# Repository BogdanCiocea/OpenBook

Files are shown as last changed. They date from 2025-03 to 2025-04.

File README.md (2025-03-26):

## PCB Description

#### ESP 
ESP32-C6-WROOM-1 is a general-purpose Wi-Fi, IEEE 802.15.4, and Bluetooth LE 
module. The rich set of peripherals and high performance make the module an 
ideal choice for smart homes, industrial automation, health care, consumer electronics, etc.

#### Absolute Maximum Ratings

| Symbol  | Parameter | Min  | Max | Unit |
| --- | --- | ---- | --- | ---- |
| VDD33 | Power supply voltage | –0.3 | 3.6 | V |
| T STORE | Storage temperature  | –40  | 105 | °C |

##### CPU and On-Chip Memory
    • ESP32-C6 embedded, 32-bit RISC-V single-core microprocessor, up to 160 MHz
    • 320 KB ROM
    • 512 KB SRAM
    • 16 KB Low-power (LP) SRAM

#### W25Q512JVEIQ

External NOR flash memory offering high-density storage.

Specifications:

• Capacity: 512 Mbit (64 MB)
• Interface: SPI (Serial Peripheral Interface)
• Operating Voltage: 3.3 V
• Usage: Firmware, configuration data, graphical assets storage

#### MCP73831

Li-Po battery charger controller for efficient battery management.

Specifications:

• Charge Current: Programmable up to ~500 mA
• Charge Voltage: Fixed 4.2 V
• Input Voltage: 5 V (typically USB)
• Features: Thermal protection, automatic charge termination, LED charge status

#### XC6220A331MR-G

Low Dropout Voltage Regulator ensuring stable power.

Specifications:

• Output Voltage: 3.3 V
• Input Voltage Range: up to 6.0 V
• Current Rating: up to 700 mA

#### MAX17048G+T10

Battery Fuel Gauge IC for precise battery monitoring.

Specifications:

• Communication Interface: I²C
• Voltage Measurement Accuracy: ±7.5 mV
• Typical Current Consumption: 23 µA
• Usage: State-of-charge monitoring, battery life estimation

#### BME688

Advanced environmental sensor providing multiple parameters.

Specifications:

• Measurements: Temperature, Humidity, Pressure, VOC gas sensing
• Communication Interface: I²C
• Operating Voltage: 1.7 V – 3.6 V

#### DS3231SN

Highly accurate Real-Time Clock (RTC) module.

Specifications:

• Accuracy: ±2 ppm (~1 min/year)
• Communication Interface: I²C
• Operating Voltage: 2.3 V – 5.5 V
• Features: Integrated battery backup for uninterrupted timekeeping

#### FH34SRJ-24S-0.5SH(99)

FFC connector for reliable display connection.

Specifications:

• Pins: 24
• Pitch: 0.5 mm
• Mount Type: Surface Mount (SMD)
• Usage: Connecting E-paper displays

#### MBR0530

Schottky diode with low forward voltage.

Specifications:

• Maximum Current: 0.5 A
• Forward Voltage Drop: ~0.3-0.4 V
• Application: Reverse voltage protection, efficient switching

#### SI1308EDL-T1-GE3

Compact N-channel MOSFET for switching applications.

Specifications:

• Voltage Rating: 20 V
• Current Rating: ~2 A
• Usage: Switching operations in display driver circuits

#### CPH3225A

Supercapacitor designed for temporary backup power.

## Pins

#### SD Card (SPI)
    * pin 7 -> pin 27 (MISO)
    * pin 3 -> pin 7 (MOSI)
    * pin 2 -> pin 4 (SS_SD)
    * pin 5 -> pin 6 (SCK)

#### 3 Buttons
    • IO/BOOT on pin 15 
    • IO/CHANGE on pin 23
    • RESET on pin 3

#### Battery Charge Level
    • pin 7 -> pin 20 (SCL)
    • pin 8 -> pin 19 (SDA)

#### BME688
    • pin 6, 8, 2 -> pin 17 (I2C_PW)
    • pin 4 -> pin 20 (SCL)
    • pin 3 -> pin 19 (SDA)

##### RTC Module DS3231SN
    • pin 4 -> pin 16 (RTC_RST)
    • pin 16 -> pin 20 (SCL)
    • pin 15 -> pin 19 (SDA)
    • pin 3 -> pin 8 (INT_RTC)
    • pin 1 -> pin 9 (32KHz)

#### USB C connector & ESD protection
    • pin 1 -> pin 14 (USB_D+)
    • pin 3 -> pin 13 (USB_D-)

## Bill Of Materials (BOM):

| Component | Quantity | Price (€) | Link | Datasheet |
| :--- | --- | --- | --- | --- |
| W25Q512JVEIQ | 1 | 5.84 | https://eu.mouser.com/ProductDetail/Winbond/W25Q512JVEIQ?qs=l7cgNqFNU1jw6svr3at6tA%3D%3D | https://eu.mouser.com/datasheet/2/949/Winbond_W25Q512JV_Datasheet-3240039.pdf |
| MAX17048G+T10 | 1 | 4.28 | https://eu.mouser.com/ProductDetail/Analog-Devices-Maxim-Integrated/MAX17048G%2bT10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 | https://eu.mouser.com/datasheet/2/609/MAX17048_MAX17049-3469099.pdf |
| ESP32-C6-WROOM-1-N8 | 1 | 2.97 | https://eu.mouser.com/ProductDetail/Espressif-Systems/ESP32-C6-WROOM-1-N8?qs=8Wlm6%252BaMh8ST02Gmwp74cw%3D%3D | https://eu.mouser.com/datasheet/2/891/Espressif_ESP32_C6_WROOM_1__Datasheet_V0_1_PRELIMI-3239987.pdf |
| 112A-TAAR-R03_ATTEND | 1 | 1.05 | https://store.comet.srl.ro/Catalogue/Product/43497/ | https://store.comet.bg/download-file.php?id=27596 |
| QWIIC_RIGHT_ANGLE | 1 | 3.75 | https://eu.mouser.com/ProductDetail/Adafruit/4208?qs=PzGy0jfpSMtbScLbr0L5dw%3D%3D | https://cdn-shop.adafruit.com/datasheets/HX8340-B_N__DS_preliminary_v01_071203.pdf |
| BD5229G-TR | 1 | 0.75 | https://eu.mouser.com/ProductDetail/ROHM-Semiconductor/BD5229G-TR?qs=4kLU8WoGk0vvnhrrYwdszw%3D%3D | https://fscdn.rohm.com/en/products/databook/datasheet/ic/power/voltage_detector/bd52xxg-e.pdf |
| 1uF capacitor | 1 | 0.13 | https://eu.mouser.com/ProductDetail/TAIYO-YUDEN/MAASL105CC7105MFCA01?qs=HFfMDpzxxd1Fn%2FInbJA7vw%3D%3D | https://eu.mouser.com/datasheet/2/396/TAIYO_YUDEN_04_27_2024_c_mlcc_A_e1-3451516.pdf |
| PGB1010603MR | 6 | 0.40 | https://eu.mouser.com/ProductDetail/Littelfuse/PGB1010603MR?qs=gu7KAQ731URLg4GSnNNN7Q%3D%3D | https://www.littelfuse.com/assetdocs/pulseguard-esd-suppressors-pgb1-datasheet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 |
| MCP73831 | 1 | 0.16 | https://eu.mouser.com/ProductDetail/Microchip-Technology/MCP73831T-5ACI-OT?qs=hH%252BOa0VZEiAcgAcEkuamXg%3D%3D | https://eu.mouser.com/datasheet/2/268/MCP73831_Family_Data_Sheet_DS20001984H-3441711.pdf |
| 200 ohm resistor | 1 | 0.10 | https://eu.mouser.com/ProductDetail/Wurth-Elektronik/560112110211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 | https://www.we-online.com/components/products/datasheet/560112110211.pdf |
| 2k ohm resistor | 1 | 0.57 | https://eu.mouser.com/ProductDetail/Vishay-Beyschlag/MCS04020D2321BE100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 | https://www.vishay.com/docs/28700/mcx0x0xpre.pdf |
| XC6220A331MR-G | 1 | 1.46 | https://eu.mouser.com/ProductDetail/Torex-Semiconductor/XC6220A331MR-G?qs=AsjdqWjXhJ8ZSWznL1J0gg%3D%3D | https://eu.mouser.com/datasheet/2/760/xc6220-3371556.pdf |
| 100uF tant capacitor | 1 | 25.19 | https://eu.mouser.com/ProductDetail/Vishay-Sprague/T97F107M035HAA?qs=kE1vTINknaW2TSWjulhndg%3D%3D | https://www.vishay.com/docs/40092/t97.pdf |
| 100k resistor | 1 | 0.30 | https://eu.mouser.com/ProductDetail/Vishay-BC-Components/NTCS0402E3104JHT?qs=8wHch9UpSvY0bmpK2FbGWQ%3D%3D | https://www.vishay.com/docs/29003/ntcs0402e3t.pdf |
| CPH3225A | 1 | 2.33 | https://eu.mouser.com/ProductDetail/Seiko-Semiconductors/CPH3225A?qs=3etwrb1wR%252BhUOph6lAO7eg%3D%3D | https://eu.mouser.com/datasheet/2/360/Seiko_Instruments_MicroBattery_E_20230330_2024Jan_-3561061.pdf |
| R_CAPACITOR | 1 | 0.12 | https://eu.mouser.com/ProductDetail/Panasonic/ERJ-2RKD15R0X?qs=8CJXEYeWfIrWZI67d3moiA%3D%3D | https://industrial.panasonic.com/cdbs/www-data/pdf/RDA0000/AOA0000C304.pdf |
| FH34SRJ-24S-0.5SH_99_ | 1 | 2.60 | https://eu.mouser.com/ProductDetail/Hirose-Connector/FH34SRJ-24S-0.5SH99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 | https://eu.mouser.com/datasheet/2/185/FH34SRJ_24S_0_5SH_99__CL0580_1255_6_99_2DDrawing_0-1615044.pdf |
| 0.1uF/50V capacitor | 1 | 0.45 | https://eu.mouser.com/ProductDetail/KYOCERA-AVX/04025C104MAT2A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 | https://eu.mouser.com/datasheet/2/40/KGM_X7R-3223212.pdf |
| 1uF/50V capacitor | 10 | 0.56 | https://eu.mouser.com/ProductDetail/TAIYO-YUDEN/MAASU32NSB7105KTCA01?qs=HFfMDpzxxd06eur8w0VYhA%3D%3D | https://eu.mouser.com/datasheet/2/396/TDK_4_24_2024_MAASU32NSB7105KTCA01_SS-3440852.pdf |
| 2k ohm resistor | 1 | 0.57 | https://eu.mouser.com/ProductDetail/Vishay-Beyschlag/MCS04020D2321BE100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 | https://www.vishay.com/docs/28700/mcx0x0xpre.pdf |
| BME688 | 1 | 14.82 | https://eu.mouser.com/ProductDetail/Bosch-Sensortec/BME680-Shuttle-Board-3.0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 | https://eu.mouser.com/datasheet/2/783/bst_bme680_sf000-2486508.pdf |
| 2.2 ohm resistor | 1 | 0.15 | https://eu.mouser.com/ProductDetail/Panasonic/ERJ-PA2J2R2X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 | https://industrial.panasonic.com/cdbs/www-data/pdf/RDO0000/AOA0000C331.pdf |
| MBR0530 | 3 | 0.18 | https://eu.mouser.com/ProductDetail/onsemi/MBR0530T3G?qs=3JMERSakebpEmdUS6GetdQ%3D%3D | https://www.onsemi.com/download/data-sheet/pdf/mbr0530t1-d.pdf |
| SI1308EDL-T1-GE3 | 1 | 0.42 | https://eu.mouser.com/ProductDetail/Vishay-Semiconductors/SI1308EDL-T1-GE3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 | https://www.vishay.com/docs/63399/si1308edl.pdf |
| 0.47 ohm resistor | 1 | 0.61 | https://eu.mouser.com/ProductDetail/ROHM-Semiconductor/UCR01MVPFLR470?qs=493kPxzlxfJor42A3tTE6g%3D%3D | https://fscdn.rohm.com/en/products/databook/datasheet/passive/resistor/chip_resistor/ucr-e.pdf |
| 4.7uF/25V capacitor | 1 | 0.27 | https://eu.mouser.com/ProductDetail/KYOCERA-AVX/04023D475MAT2A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 | https://eu.mouser.com/datasheet/2/40/cx5r-2835979.pdf |
| 68uH ind | 1 | 1.37 | https://store.comet.srl.ro/CatalogueFarnell/Product/1302649/ | https://www.we-online.com/components/products/datasheet/744043680.pdf |
| 10uF capacitor | 1 | 0.28 | https://eu.mouser.com/ProductDetail/KYOCERA-AVX/KGM05CS60J106MH?qs=9vOqFld9vZXSfhl2b2Q2gQ%3D%3D | https://eu.mouser.com/datasheet/2/40/KGM_X6S-3223173.pdf |
| SAMACSYS_PARTS_USB4110-GF-A | 1 | 1.18 | https://eu.mouser.com/ProductDetail/GCT/USB4110-GF-A?qs=KUoIvG%2F9IlYiZvIXQjyJeA%3D%3D | https://eu.mouser.com/datasheet/2/837/GCT_USB4110_Product_Drawing___20k_cycles-3455479.pdf |
| PFMF.050.1 | 1 | 0.28 | https://eu.mouser.com/ProductDetail/Schurter/PFMF.050.2?qs=1auRipcfynCums5v1iucSA%3D%3D | https://eu.mouser.com/datasheet/2/358/typ_PFMF-1275918.pdf |
| 5k1 resistor | 2 | 0.15 | https://eu.mouser.com/ProductDetail/Vishay-Beyschlag/MCS04020C5101FE000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 | https://www.vishay.com/docs/28705/mcx0x0xpro.pdf |
| Battery | 1 | 10.45 | https://www.emag.ro/acumulator-li-polymer-2500mah-3-7v-104050-243/pd/D6VB6SMBM/ | https://www.ufinebattery.com/images/upload/ufx0165-11-3-7v-2500mah-lithium-ion-battery-product-datasheet.pdf |
| Display | 1 | 44.12 | https://www.waveshare.com/7.5inch-e-paper.htm | https://files.waveshare.com/upload/6/60/7.5inch_e-Paper_V2_Specification.pdf |
| 100nF capacitor | 8 | 0.013 | https://store.comet.srl.ro/Catalogue/Product/48939/ | https://store.comet.bg/download-file.php?id=11 |
| 10k resistor | 16 | 0.19 | https://eu.mouser.com/ProductDetail/Vishay/MCS04020D1022BE000?qs=pUKx8fyJudATYWOpd0Fc%2FA%3D%3D | https://www.vishay.com/docs/28700/mcx0x0xpre.pdf |
| 4.7uF capacitor | 5 | 0.82 | https://eu.mouser.com/ProductDetail/KEMET/C0402C475K8PACTU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 | https://eu.mouser.com/datasheet/2/447/KEM_C1006_X5R_SMD-3316465.pdf |
| SD0805S020S1R0 | 2 | 0.30 | https://eu.mouser.com/ProductDetail/KYOCERA-AVX/SD0805S020S1R0?qs=jCA%252BPfw4LHbpkAoSnwrdjw%3D%3D | https://eu.mouser.com/ProductDetail/KYOCERA-AVX/SD0805S020S1R0?qs=jCA%252BPfw4LHbpkAoSnwrdjw%3D%3D |
| DMG2305UX-7 | 2 | 0.2 | https://store.comet.srl.ro/CatalogueFarnell/Product/1773598/ | https://4donline.ihs.com/images/VipMasterIC/IC/DIOD/DIOD-S-A0013043571/DIOD-S-A0013120650-1.pdf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 |

#### TOTAL: 145.79 euro

## Diagram
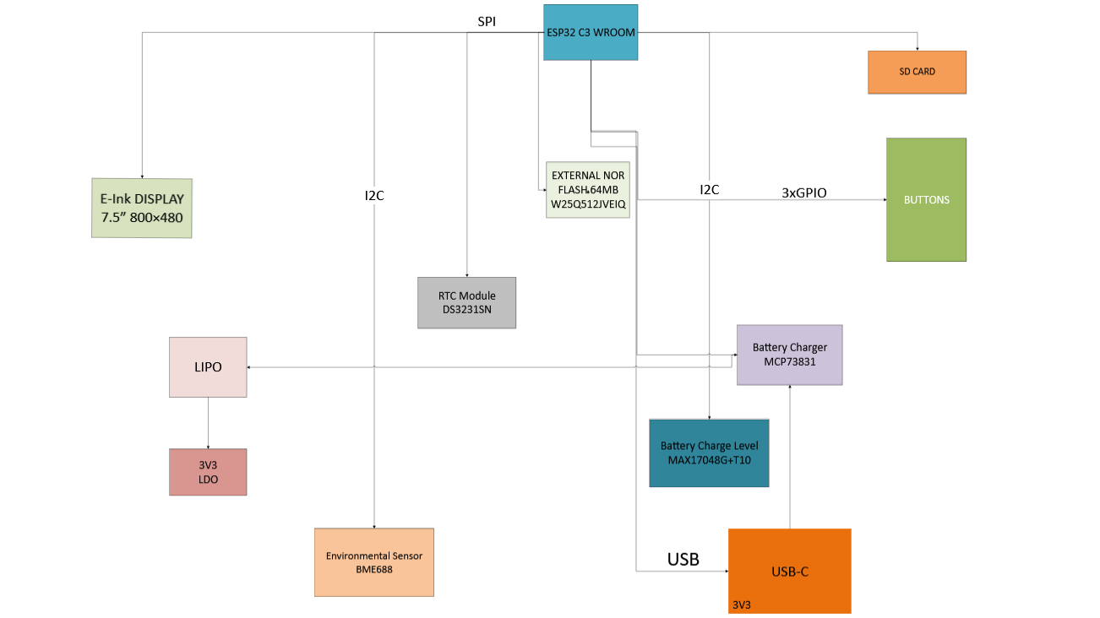
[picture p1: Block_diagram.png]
Diagram


##### Design log:
Pentru PCB am acceptat 2 erori de Board Outline Clearence deoarece asa se spune
in OCW si 4 erori de Silkscreen Clearance deoarece nu puteam face nimic sa indepartez acele erori...asta e

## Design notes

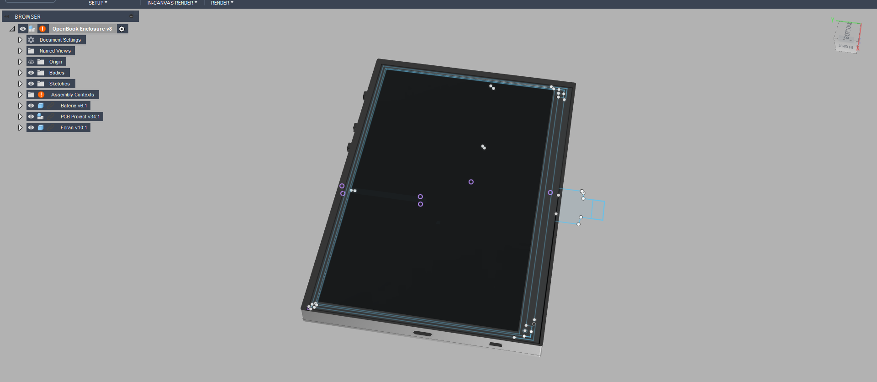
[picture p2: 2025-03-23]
Images/ebook1.png

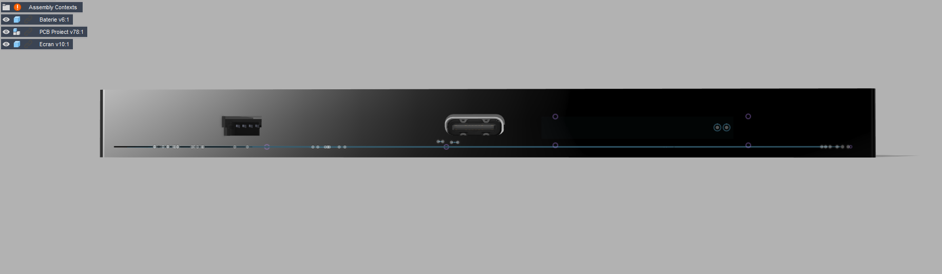
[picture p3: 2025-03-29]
Images/ebook4.png

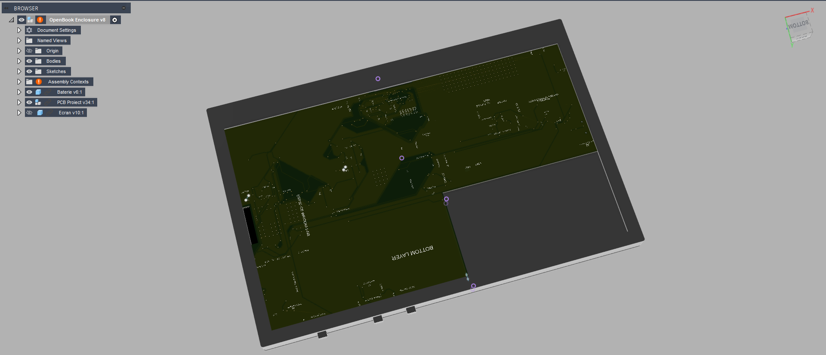
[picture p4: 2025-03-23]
Images/ebook3.png

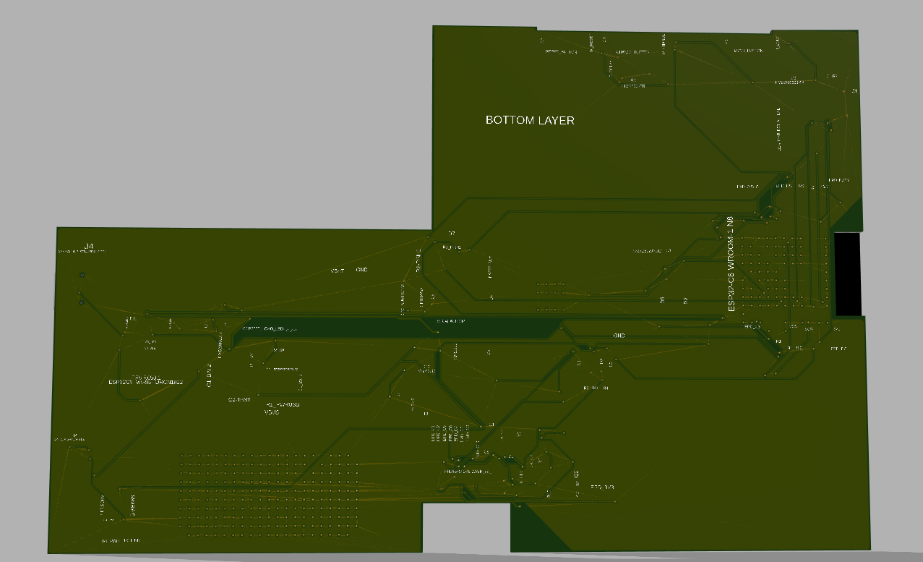
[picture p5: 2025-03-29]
Images/placuta2.png

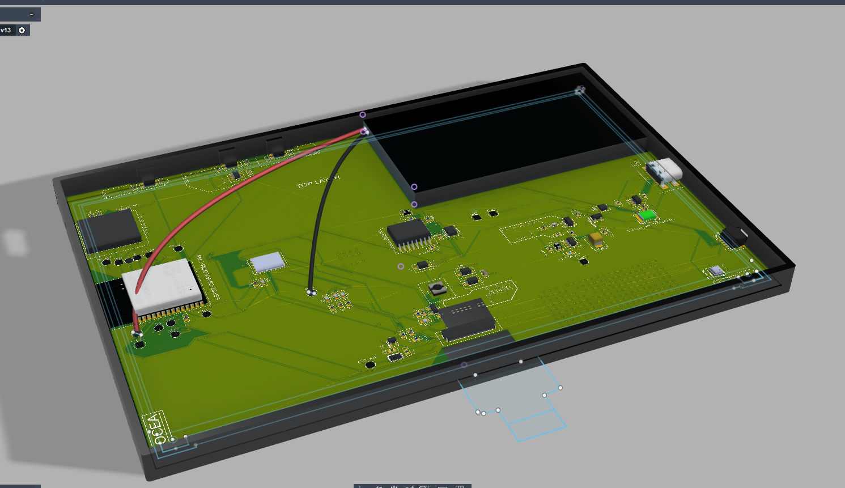
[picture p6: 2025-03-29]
Images/ebook2.png

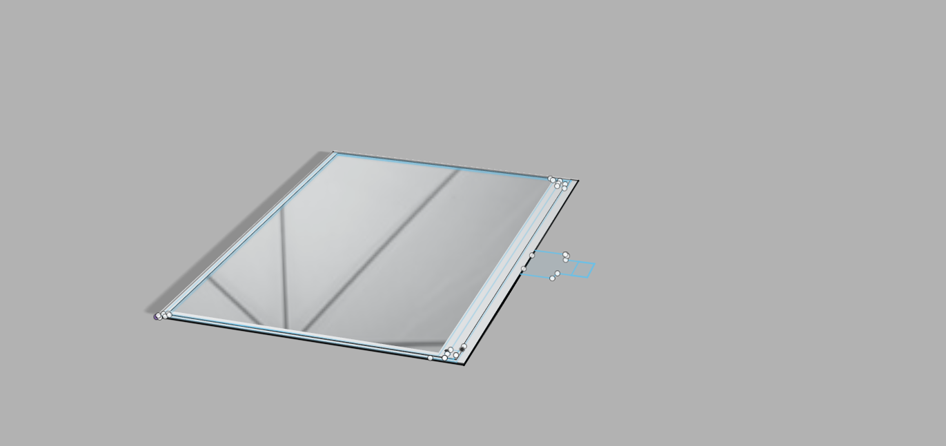
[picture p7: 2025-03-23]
Images/ecran1.png

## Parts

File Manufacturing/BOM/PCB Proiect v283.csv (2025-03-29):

Qty | Value | Device | Package | Parts | Description | ARROW_PART_NUMBER | ARROW_PRICE-STOCK | AVAILABILITY | CENTROID_NOT_SPECIFIED | CHECK_PRICES | COPYRIGHT | DATASHEET | DESCRIPTION | DIGIKEY_DESCRIPTION | DIGIKEY_PART_NUMBER | HEIGHT | LEAD_FREE | MANUFACTURER_NAME | MANUFACTURER_PART_NUMBER | MF | MFR_NAME | MOUSER_PART_NUMBER | MOUSER_PRICE-STOCK | MOUSER_TESTING_PART_NUMBER | MOUSER_TESTING_PRICE-STOCK | MP | MPN | PACKAGE | POPULARITY | PREFIX | PRICE | PROD_ID | PURCHASE-URL | ROHS | SNAPEDA_LINK | SPICEMODEL | SPICEPREFIX | TEMPERATURE_RANGE_HIGH | TEMPERATURE_RANGE_LOW | TP_SIGNAL_NAME | VALUE
1 |  | ADAFRUIT_LEDCHIP-LED0603 | ADAFRUIT_CHIP-LED0603 | CHG_LED | LED
1 |  | SJ | SJ | SJ1 | SMD solder JUMPER |  |  |  |  |  |  |  |  |  |  |  |  |  |  |  |  |  |  |  |  |  |  |  | 3
1 | 0.1uF/50V | EAGLE-LTSPICE_CC0402 | EAGLE-LTSPICE_C0402 | EPD_C5 | CAPACITOR, European symbol |  |  |  |  |  |  |  |  |  |  |  |  |  |  |  |  |  |  |  |  |  |  |  |  |  |  |  |  |  |  | NONE | C
1 | 0.47 | ESP32_WROVER_EAGLE-LTSPICE_RR0402 | ESP32_WROVER_EAGLE-LTSPICE_R0402 | R10 | RESISTOR, European symbol |  |  |  |  |  |  |  |  |  |  |  |  |  |  |  |  |  |  |  |  |  |  |  |  |  |  |  |  |  |  | NONE | R
1 | 100K | ESP32_WROVER_EAGLE-LTSPICE_RR0402 | ESP32_WROVER_EAGLE-LTSPICE_R0402 | R1_PWRUSB | RESISTOR, European symbol |  |  |  |  |  |  |  |  |  |  |  |  |  |  |  |  |  |  |  |  |  |  |  |  |  |  |  |  |  |  | NONE | R
8 | 100nF | EAGLE-LTSPICE_CC0402 | EAGLE-LTSPICE_C0402 | C1, C3, C4, C4_USB, C6, C8, C9, C_DELAY | CAPACITOR, European symbol |  |  |  |  |  |  |  |  |  |  |  |  |  |  |  |  |  |  |  |  |  |  |  |  |  |  |  |  |  |  | NONE | C
1 | 100uF TANT | RCL_CPOL-EUCT3528 | RCL_CT3528 | C2-TANT | POLARIZED CAPACITOR, European symbol |  |  |  |  |  |  |  |  |  |  |  |  |  |  |  |  |  |  |  |  |  |  |  | 0 |  |  |  |  |  |  |  | C
16 | 10K | ESP32_WROVER_EAGLE-LTSPICE_RR0402 | ESP32_WROVER_EAGLE-LTSPICE_R0402 | R1, R1_PINH, R1_PINH1, R2, R2-PINH, R2-PINH1, R3, R4, R5, R6, R7, R9, R_BOOT, R_CHANGE, R_CL1, R_RESET | RESISTOR, European symbol |  |  |  |  |  |  |  |  |  |  |  |  |  |  |  |  |  |  |  |  |  |  |  |  |  |  |  |  |  |  | NONE | R
1 | 10uF | EAGLE-LTSPICE_CC0402 | EAGLE-LTSPICE_C0402 | C5 | CAPACITOR, European symbol |  |  |  |  |  |  |  |  |  |  |  |  |  |  |  |  |  |  |  |  |  |  |  |  |  |  |  |  |  |  | NONE | C
1 | 112A-TAAR-R03_ATTEND | 112A-TAAR-R03_ATTEND | 112ATAARR03ATTEND | J1 | Micro SD Card Socket, Push-Push Type, Top Mount, SMT, H=1.83mm, 10u |  |  |  |  |  |  |  | Micro SD Card Socket | Push-Push Type | Top Mount | SMT | H=1.83mm | 10u |  |  | 1.9mm |  | ATTEND | 112A-TAAR-R03 ATTEND
1 | 15 | ESP32_WROVER_EAGLE-LTSPICE_RR0402 | ESP32_WROVER_EAGLE-LTSPICE_R0402 | R_CAPACITOR | RESISTOR, European symbol |  |  |  |  |  |  |  |  |  |  |  |  |  |  |  |  |  |  |  |  |  |  |  |  |  |  |  |  |  |  | NONE | R
1 | 1uF | EAGLE-LTSPICE_CC0402 | EAGLE-LTSPICE_C0402 | C2 | CAPACITOR, European symbol |  |  |  |  |  |  |  |  |  |  |  |  |  |  |  |  |  |  |  |  |  |  |  |  |  |  |  |  |  |  | NONE | C
9 | 1uF/50V | EAGLE-LTSPICE_CC0402 | EAGLE-LTSPICE_C0402 | EPD_C1, EPD_C2, EPD_C6, EPD_C7, EPD_C8, EPD_C9, EPD_C10, EPD_C11, EPD_C12 | CAPACITOR, European symbol |  |  |  |  |  |  |  |  |  |  |  |  |  |  |  |  |  |  |  |  |  |  |  |  |  |  |  |  |  |  | NONE | C
1 | 2.2 | ESP32_WROVER_EAGLE-LTSPICE_RR0402 | ESP32_WROVER_EAGLE-LTSPICE_R0402 | R8 | RESISTOR, European symbol |  |  |  |  |  |  |  |  |  |  |  |  |  |  |  |  |  |  |  |  |  |  |  |  |  |  |  |  |  |  | NONE | R
1 | 200 | ESP32_WROVER_EAGLE-LTSPICE_RR0402 | ESP32_WROVER_EAGLE-LTSPICE_R0402 | R1_BAT | RESISTOR, European symbol |  |  |  |  |  |  |  |  |  |  |  |  |  |  |  |  |  |  |  |  |  |  |  |  |  |  |  |  |  |  | NONE | R
2 | 20V/4.2A/52mO/1.4W | ESP32_WROVER_SPARKFUN-DISCRETESEMI_MOSFET_PCH-DMG2305UX-7 | ESP32_WROVER_SPARKFUN-DISCRETESEMI_SOT23-3 | DMG2305UX-7, Q1 | P-channel MOSFETs |  |  |  |  |  |  |  |  |  |  |  |  |  |  |  |  |  |  |  |  |  |  |  |  |  |  | TRAN-14388 |  |  |  |  |  |  |  |  | 20V/4.2A/52mO/1.4W
1 | 2K | ESP32_WROVER_EAGLE-LTSPICE_RR0402 | ESP32_WROVER_EAGLE-LTSPICE_R0402 | R2_BAT | RESISTOR, European symbol |  |  |  |  |  |  |  |  |  |  |  |  |  |  |  |  |  |  |  |  |  |  |  |  |  |  |  |  |  |  | NONE | R
1 | 3V3 | TPTP20R | TP20R | TP16 | Test pad |  |  |  |  |  |  |  |  |  |  |  |  |  |  |  |  |  |  |  |  |  |  |  | 2
5 | 4.7uF | EAGLE-LTSPICE_CC0402 | EAGLE-LTSPICE_C0402 | C1_BAT, C1_BAT1, C1_BAT2, C2_BAT, C5_USB | CAPACITOR, European symbol |  |  |  |  |  |  |  |  |  |  |  |  |  |  |  |  |  |  |  |  |  |  |  |  |  |  |  |  |  |  | NONE | C
1 | 4.7uF/25V | EAGLE-LTSPICE_CC0402 | EAGLE-LTSPICE_C0402 | C7 | CAPACITOR, European symbol |  |  |  |  |  |  |  |  |  |  |  |  |  |  |  |  |  |  |  |  |  |  |  |  |  |  |  |  |  |  | NONE | C
2 | 5k1 | ESP32_WROVER_EAGLE-LTSPICE_RR0402 | ESP32_WROVER_EAGLE-LTSPICE_R0402 | R2-USB, R2-USB1 | RESISTOR, European symbol |  |  |  |  |  |  |  |  |  |  |  |  |  |  |  |  |  |  |  |  |  |  |  |  |  |  |  |  |  |  | NONE | R
1 | 68uH | 744043680IND_4828-WE-TPC_WRE | IND_4828-WE-TPC_WRE | L1 |  |  |  |  |  |  | Copyright (C) 2024 Ultra Librarian. All rights reserved. |  |  |  |  |  |  |  | 744043680 |  | Wurth Electronics
1 | BD5229G-TR | BD5229G-TR | SOT95P280X125-5N | IC2 | Voltage Detector with Adjustable Delay Time: CMOS processes are utilized to develop high precision, low current consumption CMOS reset ICs that allow arbitrary setting of the delay time. The extensive lineup includes both Nch Open Drain and CMOS output types in a wide range of detection voltages (from 2.3V to 6.0V, in 0.1V steps), enabling selection of the ideal solution based on customer requirements. In addition, the entire series is of course both lead-free and RoHS-compliant. |  |  |  |  |  |  |  | Voltage Detector with Adjustable Delay Time: CMOS processes are utilized to develop high precision | low current consumption CMOS reset ICs that allow arbitrary setting of the delay time. The extensive lineup includes both Nch Open Drain and CMOS output types in a wide range of detection voltages (from 2.3V to 6.0V | in 0.1V steps) | enabling selection of the ideal solution based on customer requirements. In addition | the entire series is of course both lead-free and RoHS-compliant. |  |  | 1.25mm |  | ROHM Semiconductor | BD5229G-TR |  |  | 755-BD5229G-TR | https://www.mouser.co.uk/ProductDetail/ROHM-Semiconductor/BD5229G-TR?qs=4kLU8WoGk0vvnhrrYwdszw%3D%3D
1 | BME688 | ESP32_WROVER_BME680_BME680 | ESP32_WROVER_BME680_PSON80P300X300X100-8N | SENSOR2 | Integrated Environmental Unit |  |  | Unavailable |  |  |  |  | Integrated Environmental Unit |  |  |  |  |  |  | Bosch Sensortec |  |  |  |  |  | BME680 |  | LGA-8 Bosch Tools |  |  | None
3 | BUTTON_CUSYOMV1 | BUTTON_CUSYOMV1 | MYBUTTON | BOOT_BUTTON, CHANGE_BUTTON, RESET_BUTTON
1 | CPH3225A | CPH3225A | CAPCP3225X100N | C10_SUPERCAP | Cap 0.011F 3.3V 1210 Flat Check availability |  |  | Not in stock |  | https://www.snapeda.com/parts/CPH3225A/Seiko+Instruments/view-part/?ref=eda |  |  | 11 mF (EDLC) Supercapacitor 3.3 V 1210 (3225 Metric) - - |  |  |  |  |  |  | Seiko Instruments |  |  |  |  |  | CPH3225A |  | 1210 Seiko |  |  | None |  | https://www.snapeda.com/api/url_track_click_mouser/?unipart_id=562593&manufacturer=Seiko Instruments&part_name=CPH3225A&search_term=None |  | https://www.snapeda.com/parts/CPH3225A/Seiko+Instruments/view-part/?ref=snap
1 | DS3231SN# | DS3231SN# | SOIC127P1032X265-16N | U4 | Real Time Clock Serial 16-Pin SOIC W T/R Check availability |  |  | In Stock |  | https://www.snapeda.com/parts/DS3231SN%23/Analog+Devices/view-part/?ref=eda |  |  | Extremely Accurate I²C-Integrated RTC/TCXO/Crystal |  |  |  |  |  |  | Analog Devices |  |  |  |  |  | DS3231SN# |  | SOIC-16 Maxim |  |  | None |  | https://www.snapeda.com/api/url_track_click_mouser/?unipart_id=99048&manufacturer=Analog Devices&part_name=DS3231SN#&search_term=None |  | https://www.snapeda.com/parts/DS3231SN%23/Analog+Devices/view-part/?ref=snap
1 | EPD_3V3 | TPTP20R | TP20R | TP17 | Test pad |  |  |  |  |  |  |  |  |  |  |  |  |  |  |  |  |  |  |  |  |  |  |  | 2
1 | EPD_3V3_C | TPTP20R | TP20R | TP13 | Test pad |  |  |  |  |  |  |  |  |  |  |  |  |  |  |  |  |  |  |  |  |  |  |  | 2
1 | EPD_BUSY | TPTP20R | TP20R | TP9 | Test pad |  |  |  |  |  |  |  |  |  |  |  |  |  |  |  |  |  |  |  |  |  |  |  | 2
1 | EPD_CS | TPTP20R | TP20R | TP10 | Test pad |  |  |  |  |  |  |  |  |  |  |  |  |  |  |  |  |  |  |  |  |  |  |  | 2
1 | EPD_DC | TPTP20R | TP20R | TP11 | Test pad |  |  |  |  |  |  |  |  |  |  |  |  |  |  |  |  |  |  |  |  |  |  |  | 2
1 | EPD_RST | TPTP20R | TP20R | TP12 | Test pad |  |  |  |  |  |  |  |  |  |  |  |  |  |  |  |  |  |  |  |  |  |  |  | 2
1 | ESP32-C6-WROOM-1-N8 | ESP32-C6-WROOM-1-N8 | XCVR_ESP32-C6-WROOM-1-N8 | U1 | Check availability |  |  | In Stock |  | https://www.snapeda.com/parts/ESP32-C6-WROOM-1-N8/Espressif+Systems/view-part/?ref=eda |  |  | Multiprotocol Modules ESP32-C6 module | Wi-Fi 6 in 2.4 GHz band | Bluetooth 5 | Zigbee 3.0 and Thread. ESP34-WROOM Compatible - ENGINEERING SAMPLE |  |  |  |  |  |  | Espressif Systems |  |  |  |  |  | ESP32-C6-WROOM-1-N8 |  | None |  |  | None |  |  |  | https://www.snapeda.com/parts/ESP32-C6-WROOM-1-N8/Espressif+Systems/view-part/?ref=snap
1 | ESP32C6_VARISTORCN1812 | ESP32C6_VARISTORCN1812 | ESP32C6_VARISTOR_CT/CN1812 | PFMF.050.1 | VARISTOR |  |  |  |  |  |  |  |  |  |  |  |  |  |  |  |  |  |  |  |  |  |  |  | 0
1 | ESP32_WROVER_AVX---SD0805S020S1R0_AVX_SD0805S020S1R0_0_0AVX_SD0805S020S1R0_0_0 | ESP32_WROVER_AVX---SD0805S020S1R0_AVX_SD0805S020S1R0_0_0AVX_SD0805S020S1R0_0_0 | ESP32_WROVER_AVX---SD0805S020S1R0_AVX_SD0805S020S1R0_0 | SD0805S020S1R0 | Schottky Barrier Rectifier Diode |  |  |  | No |  |  | http://datasheets.avx.com/schottky.pdf |  | DIODE SCHOTTKY 20V 1A 0805 | 478-7800-1-ND |  | yes |  |  | AVX |  | 581-SD0805S020S1R0 |  |  |  |  |  | 0805 (2012 metric) |  | D |  |  |  | yes |  |  |  | +125°C | -55°C
1 | ESP32_WROVER_SPARKFUN-IC-POWER_MCP73831 | ESP32_WROVER_SPARKFUN-IC-POWER_MCP73831 | ESP32_WROVER_SPARKFUN-IC-POWER_SOT23-5 | MCP73831 | MCP73831T Li-Ion, Li-Pol Controller |  |  |  |  |  |  |  |  |  |  |  |  |  |  |  |  |  |  |  |  |  |  |  |  |  |  | IC-09995
1 | FH34SRJ-24S-0.5SH_99_ | FH34SRJ-24S-0.5SH_99_ | FH34SRJ24S05SH99 | J3 | (0.50mm) Surface Mount, Right Angle |  |  |  |  |  |  |  | 24 Position FFC | FPC Connector Contacts | (0.50mm) Surface Mount | Right Angle |  |  | 1.1mm |  | Hirose | FH34SRJ-24S-0.5SH(99) |  |  | 798-FH34SRJ24S05SH99 | https://www.mouser.co.uk/ProductDetail/Hirose-Connector/FH34SRJ-24S-0.5SH99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
2 | GND | TPTP20R | TP20R | TP4, TP5 | Test pad |  |  |  |  |  |  |  |  |  |  |  |  |  |  |  |  |  |  |  |  |  |  |  | 2
1 | INT_RTC | TPTP20R | TP20R | TP15 | Test pad |  |  |  |  |  |  |  |  |  |  |  |  |  |  |  |  |  |  |  |  |  |  |  | 2
1 | MAX17048G+T10 | MAX17048G+T10 | SON50P200X200X80-9N | U2 | Check availability |  |  | In Stock |  | https://www.snapeda.com/parts/MAX17048G+T10/Analog+Devices/view-part/?ref=eda |  |  | 3µA 1-Cell/2-Cell Fuel Gauge with ModelGauge |  |  |  |  |  |  | Analog Devices |  |  |  |  |  | MAX17048G+T10 |  | TDFN-8 Maxim |  |  | None |  | https://www.snapeda.com/api/url_track_click_mouser/?unipart_id=329239&manufacturer=Analog Devices&part_name=MAX17048G+T10&search_term=None |  | https://www.snapeda.com/parts/MAX17048G+T10/Analog+Devices/view-part/?ref=snap
3 | MBR0530 | MBR0530 | SOD3716X135N | D8, D9, D10 | ON SEMICONDUCTOR - MBR0530 - DIODE, SCHOTTKY, 0.5A, 30V, SOD-123 |  |  | In Stock |  | https://www.snapeda.com/parts/MBR0530/Onsemi/view-part/?ref=eda |  |  | Diode Schottky 30 V 500mA Surface Mount SOD-123 |  |  |  |  |  |  | ON Semiconductor |  |  |  |  |  | MBR0530 |  | SOD-123-2 ON Semiconductor |  |  | None |  | https://www.snapeda.com/api/url_track_click_mouser/?unipart_id=179458&manufacturer=ON Semiconductor&part_name=MBR0530&search_term=None |  | https://www.snapeda.com/parts/MBR0530/Onsemi/view-part/?ref=snap
1 | MISO | TPTP20R | TP20R | TP6 | Test pad |  |  |  |  |  |  |  |  |  |  |  |  |  |  |  |  |  |  |  |  |  |  |  | 2
1 | MOSI | TPTP20R | TP20R | TP7 | Test pad |  |  |  |  |  |  |  |  |  |  |  |  |  |  |  |  |  |  |  |  |  |  |  | 2
6 | PGB1010603MR | PGB1010603MR | DIOC1608X36N | D1, D2, D3, D4, D5, D6 | Check availability |  |  | In Stock |  | https://www.snapeda.com/parts/PGB1010603MR/Littelfuse/view-part/?ref=eda |  |  | 150V (Typ) Clamp - Ipp Tvs Diode Surface Mount 0603 (1608 Metric) |  |  |  |  |  |  | Littelfuse Inc. |  |  |  |  |  | PGB1010603MR |  | 0603 Littelfuse Inc. |  |  | None |  | https://www.snapeda.com/api/url_track_click_mouser/?unipart_id=5659453&manufacturer=Littelfuse Inc.&part_name=PGB1010603MR&search_term=None |  | https://www.snapeda.com/parts/PGB1010603MR/Littelfuse/view-part/?ref=snap
1 | QWIIC_RIGHT_ANGLE | QWIIC_CONNECTORJS-1MM | JST04_1MM_RA | J2 | SparkFun I2C Standard Qwiic Connector |  |  |  |  |  |  |  |  |  |  |  |  |  |  |  |  |  |  |  |  |  |  |  |  |  |  | CONN-13694 |  |  |  |  |  |  |  |  | QWIIC_RIGHT_ANGLE
1 | RX | TPTP20R | TP20R | TP2 | Test pad |  |  |  |  |  |  |  |  |  |  |  |  |  |  |  |  |  |  |  |  |  |  |  | 2
1 | SAMACSYS_PARTS_USB4110-GF-A | SAMACSYS_PARTS_USB4110-GF-A | SAMACSYS_PARTS_USB4110GFA | J4 | CONN USB 2.0 TYPE-C R/A SMT |  |  |  |  |  |  |  | CONN USB 2.0 TYPE-C R/A SMT |  |  | 3.26mm |  | GCT (GLOBAL CONNECTOR TECHNOLOGY) | USB4110-GF-A |  |  | 640-USB4110-GF-A | https://www.mouser.co.uk/ProductDetail/GCT/USB4110-GF-A?qs=KUoIvG%2F9IlYiZvIXQjyJeA%3D%3D
1 | SCK | TPTP20R | TP20R | TP8 | Test pad |  |  |  |  |  |  |  |  |  |  |  |  |  |  |  |  |  |  |  |  |  |  |  | 2
1 | SD0805S020S1R0 | ESP32_WROVER_AVX---SD0805S020S1R0_AVX_SD0805S020S1R0_0_0AVX_SD0805S020S1R0_0_0 | ESP32_WROVER_AVX---SD0805S020S1R0_AVX_SD0805S020S1R0_0 | D7 | Schottky Barrier Rectifier Diode |  |  |  | No |  |  | http://datasheets.avx.com/schottky.pdf |  | DIODE SCHOTTKY 20V 1A 0805 | 478-7800-1-ND |  | yes |  |  | AVX |  | 581-SD0805S020S1R0 |  |  |  |  |  | 0805 (2012 metric) |  | D |  |  |  | yes |  |  |  | +125°C | -55°C
1 | SI1308EDL-T1-GE3 | SI1308EDL-T1-GE3 | SOT65P210X110-3N | Q2 | MOSFET N-Ch 30V 1.5A TrenchFET SC70 Vishay Si1308EDL-T1-GE3 N-channel MOSFET Transistor, 1.5 A, 30 V, 3-Pin SC-70 |  |  | In Stock |  | https://www.snapeda.com/parts/SI1308EDL-T1-GE3/Vishay+Siliconix/view-part/?ref=eda |  |  | Si1308EDL-T1-GE3 N-channel MOSFET Transistor | 1.5 A | 30 V | 3-Pin SC-70 | Siliconix / Vishay SI1308EDL-T1-GE3 |  |  |  |  |  |  | Vishay Siliconix |  |  |  |  |  | SI1308EDL-T1-GE3 |  | SOT-323 Vishay Semiconductor |  |  | None |  | https://www.snapeda.com/api/url_track_click_mouser/?unipart_id=274603&manufacturer=Vishay Siliconix&part_name=SI1308EDL-T1-GE3&search_term=None |  | https://www.snapeda.com/parts/SI1308EDL-T1-GE3/Vishay+Siliconix/view-part/?ref=snap
1 | TX | TPTP20R | TP20R | TP1 | Test pad |  |  |  |  |  |  |  |  |  |  |  |  |  |  |  |  |  |  |  |  |  |  |  | 2
1 | USBLC6-2SC6Y | USBLC6-2SC6Y | SOT95P280X145-6N | D11 | Low Cap. ESD Protection Auto SOT-23-6 STMicroelectronics USBLC6-2SC6Y, Dual Uni-Directional TVS Diode Array, 6-Pin SOT-23 |  |  | In Stock |  | https://www.snapeda.com/parts/USBLC6-2SC6Y/STMicroelectronics/view-part/?ref=eda |  |  | 17V Clamp 5A (8/20µs) Ipp Tvs Diode Surface Mount SOT-23-6 |  |  |  |  |  |  | STMicroelectronics |  |  |  |  |  | USBLC6-2SC6Y |  | SOT-23-6 STMicroelectronics |  |  | None |  |  |  | https://www.snapeda.com/parts/USBLC6-2SC6Y/STMicroelectronics/view-part/?ref=snap
1 | VBAT | TPTP20R | TP20R | TP3 | Test pad |  |  |  |  |  |  |  |  |  |  |  |  |  |  |  |  |  |  |  |  |  |  |  | 2
1 | VBUS | TPTP20R | TP20R | TP14 | Test pad |  |  |  |  |  |  |  |  |  |  |  |  |  |  |  |  |  |  |  |  |  |  |  | 2
1 | W25Q512JVEIQ | W25Q512JVEIQ | SON127P600X800X80-9N | U3 | Check availability |  |  | In Stock |  | https://www.snapeda.com/parts/W25Q512JVEIQ/Winbond+Electronics/view-part/?ref=eda |  |  | FLASH - NOR Memory IC 512Mb (64M x 8) SPI - Quad I/O 133 MHz 8-WSON (8x6) |  |  |  |  |  |  | Winbond Electronics |  |  |  |  |  | W25Q512JVEIQ |  | Package |  |  | None |  |  |  | https://www.snapeda.com/parts/W25Q512JVEIQ/Winbond+Electronics/view-part/?ref=snap
1 | XC6220A331MR-G | XC6220A331MR-G | SOT95P280X120-5N | IC1 | LDO Voltage Regulators |  |  |  |  |  |  |  | LDO Voltage Regulators |  |  | 1.2mm |  | Torex | XC6220A331MR-G |  |  | 865-XC6220A331MR-G | https://www.mouser.co.uk/ProductDetail/Torex-Semiconductor/XC6220A331MR-G?qs=AsjdqWjXhJ8ZSWznL1J0gg%3D%3D

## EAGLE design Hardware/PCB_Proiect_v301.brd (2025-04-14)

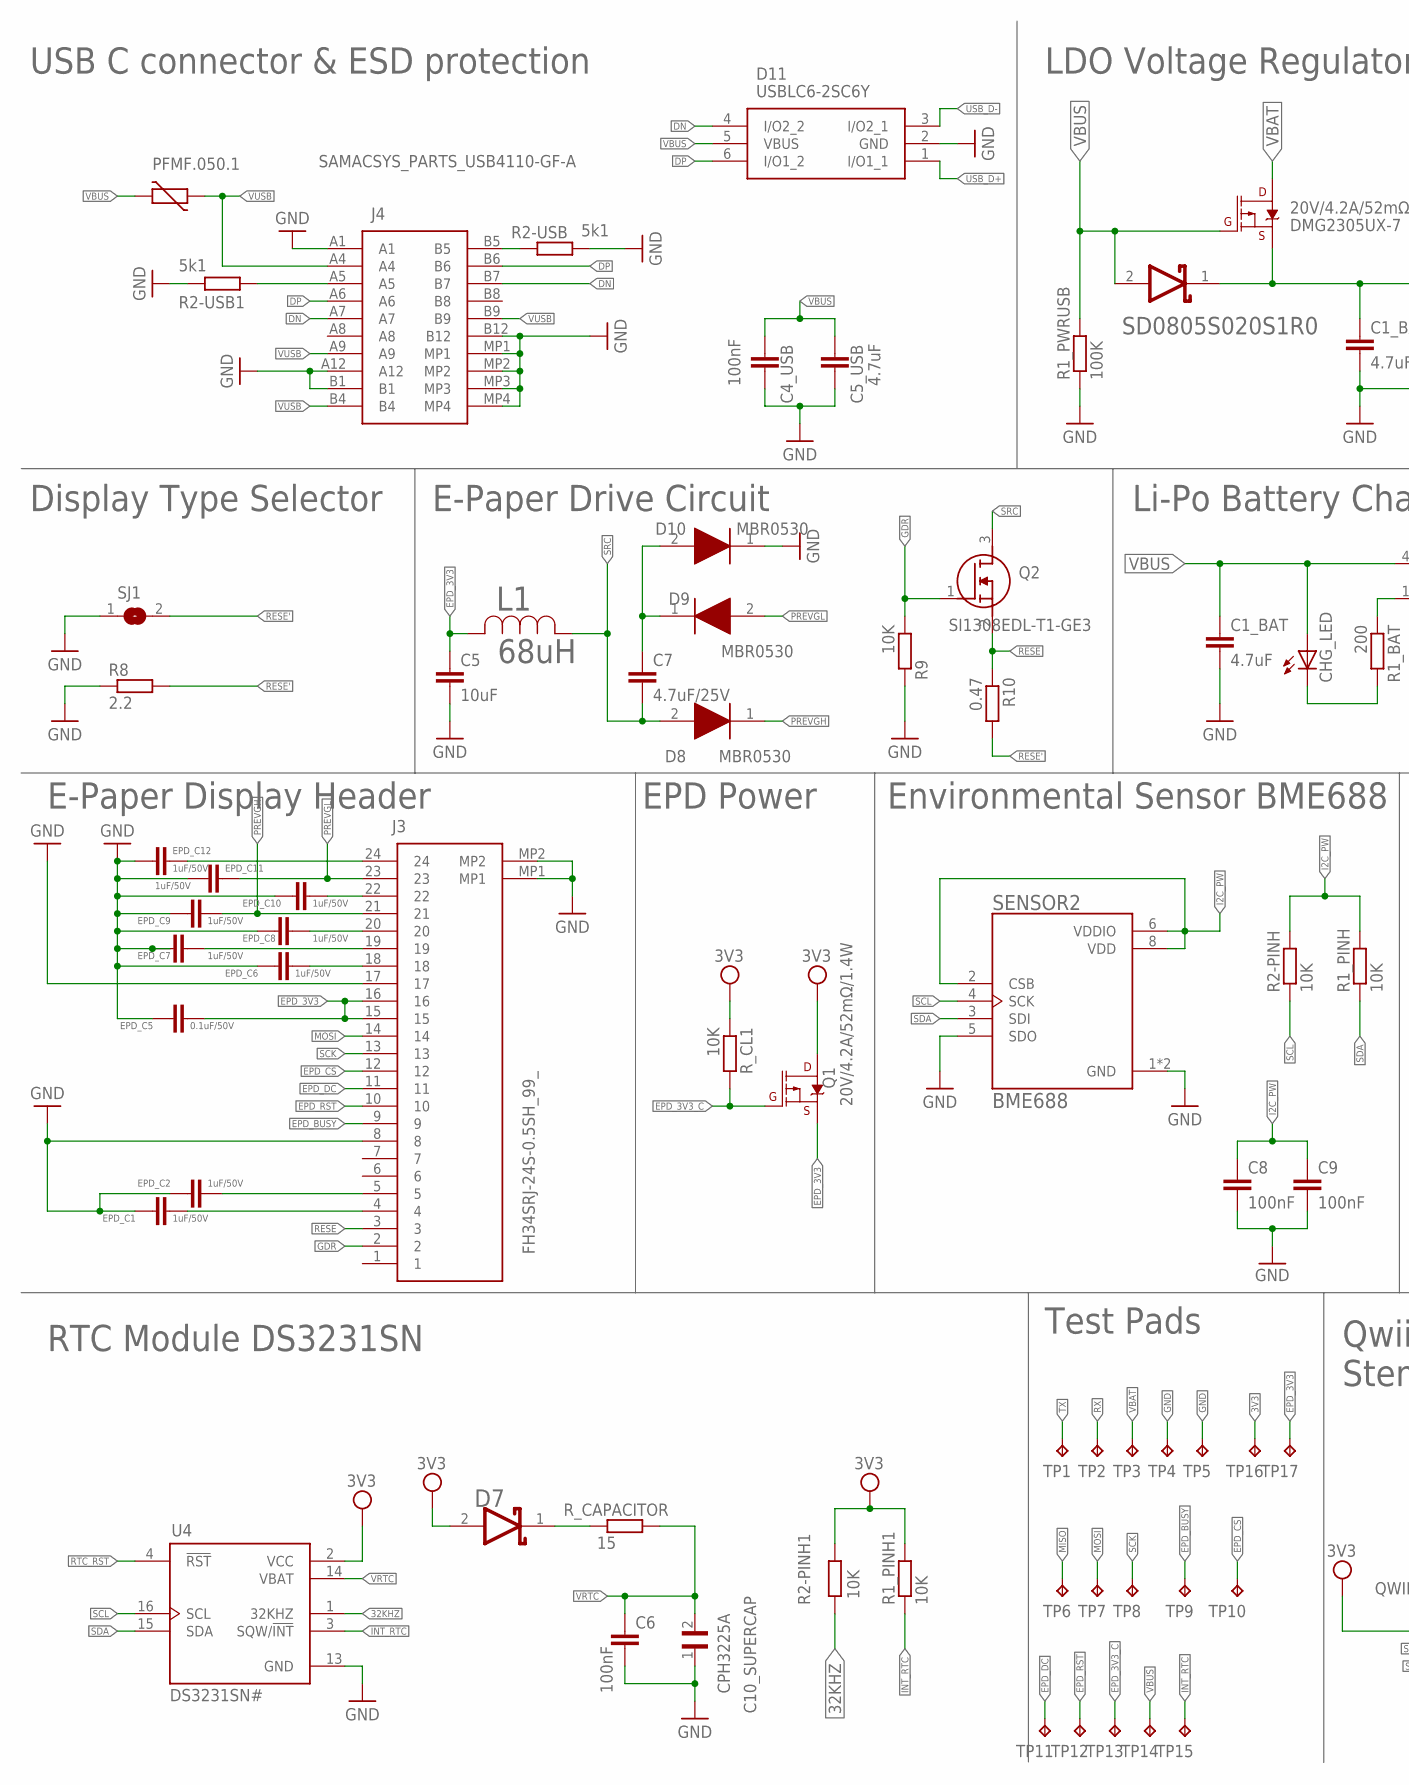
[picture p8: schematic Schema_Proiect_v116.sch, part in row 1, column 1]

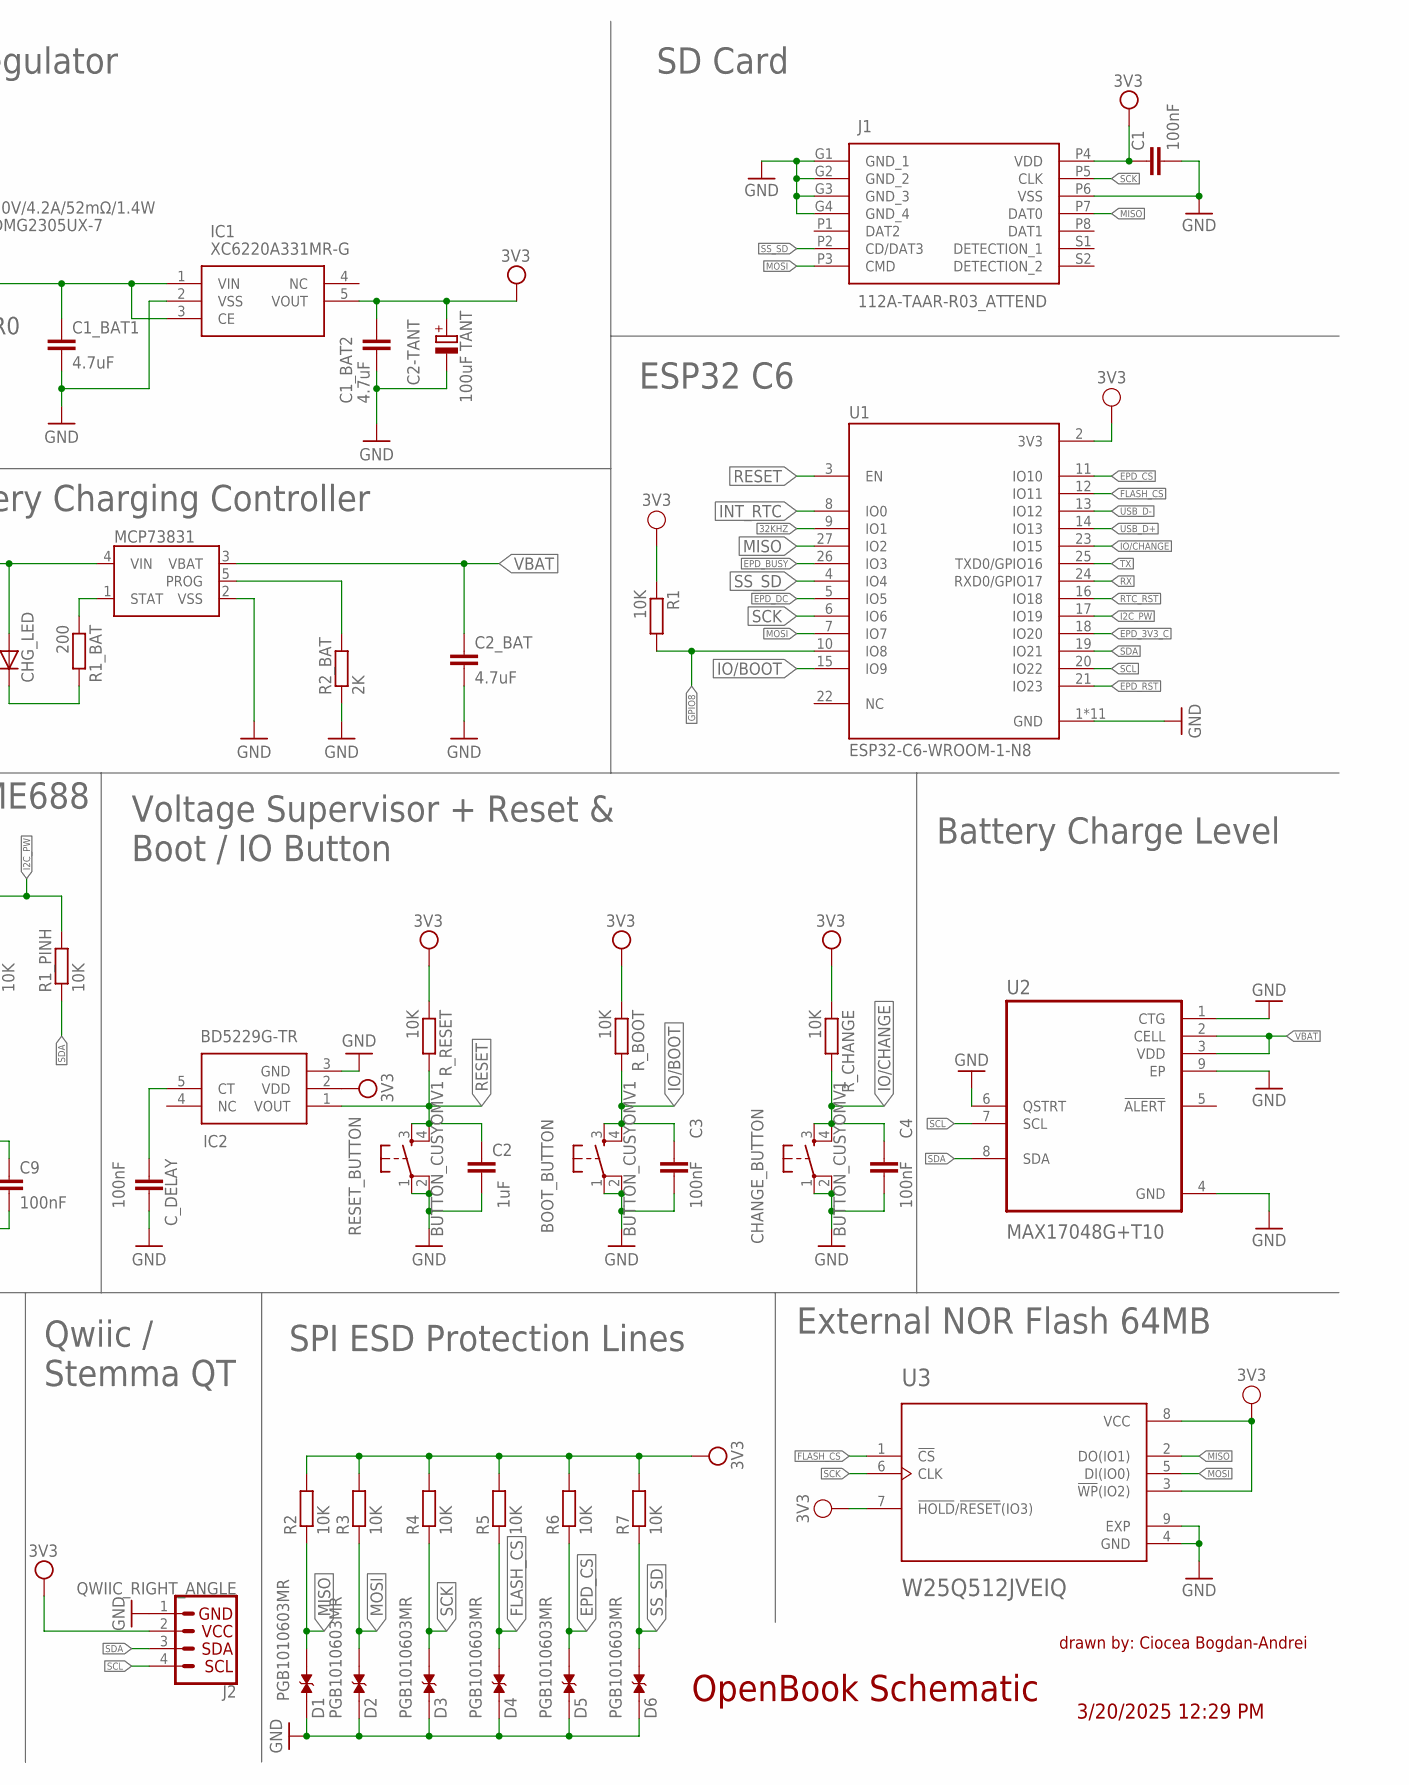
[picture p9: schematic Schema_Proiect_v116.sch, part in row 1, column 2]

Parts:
BOOT_BUTTON: BUTTON_CUSYOMV1; MYBUTTON
C1, C3, C4, C4_USB, C6, C8, C9: 100nF; EAGLE-LTSPICE_C0402
C1_BAT, C1_BAT1, C1_BAT2, C2_BAT, C5_USB: 4.7uF; EAGLE-LTSPICE_C0402
C2: 1uF; EAGLE-LTSPICE_C0402
C2-TANT: 100uF TANT; RCL_CT3528
C5: 10uF; EAGLE-LTSPICE_C0402
C7: 4.7uF/25V; EAGLE-LTSPICE_C0402
C10_SUPERCAP: CPH3225A; CAPCP3225X100N
CHANGE_BUTTON: BUTTON_CUSYOMV1; MYBUTTON
CHG_LED: ADAFRUIT_LEDCHIP-LED0603; ADAFRUIT_CHIP-LED0603
C_DELAY: 100nF; EAGLE-LTSPICE_C0402
D1, D2, D3, D4, D5, D6: PGB1010603MR; DIOC1608X36N
D7: SD0805S020S1R0; ESP32_WROVER_AVX---SD0805S020S1R0_AVX_SD0805S020S1R0_0
D8, D9, D10: MBR0530; SOD3716X135N
D11: USBLC6-2SC6Y; SOT95P280X145-6N
DMG2305UX-7: 20V/4.2A/52mΩ/1.4W; ESP32_WROVER_SPARKFUN-DISCRETESEMI_SOT23-3
EPD_C1, EPD_C2, EPD_C6, EPD_C7, EPD_C8, EPD_C9, EPD_C10, EPD_C11, EPD_C12: 1uF/50V; EAGLE-LTSPICE_C0402
EPD_C5: 0.1uF/50V; EAGLE-LTSPICE_C0402
IC1: XC6220A331MR-G; SOT95P280X120-5N
IC2: BD5229G-TR; SOT95P280X125-5N
J1: 112A-TAAR-R03_ATTEND; 112ATAARR03ATTEND
J2: QWIIC_RIGHT_ANGLE; JST04_1MM_RA
J3: FH34SRJ-24S-0.5SH_99_; FH34SRJ24S05SH99
J4: SAMACSYS_PARTS_USB4110-GF-A; SAMACSYS_PARTS_USB4110GFA
L1: 68uH; IND_4828-WE-TPC_WRE
MCP73831: ESP32_WROVER_SPARKFUN-IC-POWER_MCP73831; ESP32_WROVER_SPARKFUN-IC-POWER_SOT23-5
PFMF.050.1: ESP32C6_VARISTORCN1812; ESP32C6_VARISTOR_CT/CN1812
Q1: 20V/4.2A/52mΩ/1.4W; ESP32_WROVER_SPARKFUN-DISCRETESEMI_SOT23-3
Q2: SI1308EDL-T1-GE3; SOT65P210X110-3N
R1, R1_PINH, R1_PINH1, R2, R2-PINH, R2-PINH1, R3, R4, R5, R6, R7, R9: 10K; ESP32_WROVER_EAGLE-LTSPICE_R0402
R1_BAT: 200; ESP32_WROVER_EAGLE-LTSPICE_R0402
R1_PWRUSB: 100K; ESP32_WROVER_EAGLE-LTSPICE_R0402
R2-USB, R2-USB1: 5k1; ESP32_WROVER_EAGLE-LTSPICE_R0402
R2_BAT: 2K; ESP32_WROVER_EAGLE-LTSPICE_R0402
R8: 2.2; ESP32_WROVER_EAGLE-LTSPICE_R0402
R10: 0.47; ESP32_WROVER_EAGLE-LTSPICE_R0402
RESET_BUTTON: BUTTON_CUSYOMV1; MYBUTTON
R_BOOT: 10K; ESP32_WROVER_EAGLE-LTSPICE_R0402
R_CAPACITOR: 15; ESP32_WROVER_EAGLE-LTSPICE_R0402
R_CHANGE: 10K; ESP32_WROVER_EAGLE-LTSPICE_R0402
R_CL1: 10K; ESP32_WROVER_EAGLE-LTSPICE_R0402
R_RESET: 10K; ESP32_WROVER_EAGLE-LTSPICE_R0402
SD0805S020S1R0: ESP32_WROVER_AVX---SD0805S020S1R0_AVX_SD0805S020S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; ESP32_WROVER_AVX---SD0805S020S1R0_AVX_SD0805S020S1R0_0
SENSOR2: BME688; ESP32_WROVER_BME680_PSON80P300X300X100-8N
SJ1: SJ
TP1: TX; TP20R
TP2: RX; TP20R
TP3: VBAT; TP20R
TP4, TP5: GND; TP20R
TP6: MISO; TP20R
TP7: MOSI; TP20R
TP8: SCK; TP20R
TP9: EPD_BUSY; TP20R
TP10: EPD_CS; TP20R
TP11: EPD_DC; TP20R
TP12: EPD_RST; TP20R
TP13: EPD_3V3_C; TP20R
TP14: VBUS; TP20R
TP15: INT_RTC; TP20R
TP16: 3V3; TP20R
TP17: EPD_3V3; TP20R
U1: ESP32-C6-WROOM-1-N8; XCVR_ESP32-C6-WROOM-1-N8
U2: MAX17048G+T10; SON50P200X200X80-9N
U3: W25Q512JVEIQ; SON127P600X800X80-9N
U4: DS3231SN#; SOIC127P1032X265-16N

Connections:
3V3: C1.1, C1_BAT2.1, C2-TANT.+, D7.2 (ANODE), IC1.5 (VOUT), IC2.2 (VDD), J1.P4 (VDD), J2.2, Q1.3 (D), R1.1, R1_PINH1.2, R2.2, R2-PINH1.1, R3.2, R4.2, R5.2, R6.2, R7.2, R_BOOT.1, R_CHANGE.1, R_CL1.1, R_RESET.1, TP16.TP, U1.2 (3V3), U3.3 (!WP!(IO2)), U3.7 (!HOLD!/!RESET!(IO3)), U3.8 (VCC), U4.2 (VCC)
32KHZ: R2-PINH1.2, U1.9 (IO1), U4.1 (32KHZ)
DN: D11.4 (I/O2_2), J4.A7, J4.B7
DP: D11.6 (I/O1_2), J4.A6, J4.B6
EPD_3V3: C5.1, EPD_C5.1, J3.15, J3.16, L1.2, Q1.2 (S), TP17.TP
EPD_3V3_C: Q1.1 (G), R_CL1.2, TP13.TP, U1.18 (IO20)
EPD_BUSY: J3.9, TP9.TP, U1.26 (IO3)
EPD_CS: D5.2, J3.12, R6.1, TP10.TP, U1.11 (IO10)
EPD_DC: J3.11, TP11.TP, U1.5 (IO5)
EPD_RST: J3.10, TP12.TP, U1.21 (IO23)
FLASH_CS: D4.2, R5.1, U1.12 (IO11), U3.1 (!CS)
GDR: J3.2, Q2.1 (G), R9.1
GND: BOOT_BUTTON.1, BOOT_BUTTON.2, C1.2, C1_BAT.2, C1_BAT1.2, C1_BAT2.2, C2.2, C2-TANT.-, C2_BAT.2, C3.2, C4.2, C4_USB.2, C5.2, C5_USB.2, C6.2, C8.2, C9.2, C10_SUPERCAP.1, CHANGE_BUTTON.1, CHANGE_BUTTON.2, C_DELAY.2, D1.1, D2.1, D3.1, D4.1, D5.1, D6.1, D10.1 (K), D11.2 (GND), EPD_C1.2, EPD_C2.2, EPD_C5.2, EPD_C6.2, EPD_C7.2, EPD_C8.2, EPD_C9.2, EPD_C10.2, EPD_C11.2, EPD_C12.2, IC1.2 (VSS), IC2.3 (GND), J1.G1 (GND_1), J1.G2 (GND_2), J1.G3 (GND_3), J1.G4 (GND_4), J1.P6 (VSS), J2.1, J3.8, J3.17, J3.MP1, J3.MP2, J4.A1, J4.A12, J4.B1, J4.B12, J4.MP1, J4.MP2, J4.MP3, J4.MP4, MCP73831.2 (VSS), R1_PWRUSB.1, R2-USB.2, R2-USB1.1, R2_BAT.1, R8.1, R9.2, RESET_BUTTON.1, RESET_BUTTON.2, SENSOR2.1 (GND), SENSOR2.5 (SDO), SENSOR2.7 (GND), SJ1.1, TP4.TP, TP5.TP, U1.1 (GND), U1.28 (GND), U1.29_1 (GND), U1.29_2 (GND), U1.29_3 (GND), U1.29_4 (GND), U1.29_5 (GND), U1.29_6 (GND), U1.29_7 (GND), U1.29_8 (GND), U1.29_9 (GND), U2.1 (CTG), U2.4 (GND), U2.6 (QSTRT), U2.9 (EP), U3.4 (GND), U3.9 (EXP), U4.13 (GND)
GPIO8: R1.2, U1.10 (IO8)
I2C_PW: C8.1, C9.1, R1_PINH.2, R2-PINH.2, SENSOR2.2 (CSB), SENSOR2.6 (VDDIO), SENSOR2.8 (VDD), U1.17 (IO19)
INT_RTC: R1_PINH1.1, TP15.TP, U1.8 (IO0), U4.3 (SQW/!INT)
IO/BOOT: BOOT_BUTTON.3, BOOT_BUTTON.4, C3.1, R_BOOT.2, U1.15 (IO9)
IO/CHANGE: C4.1, CHANGE_BUTTON.3, CHANGE_BUTTON.4, R_CHANGE.2, U1.23 (IO15)
MISO: D1.2, J1.P7 (DAT0), R2.1, TP6.TP, U1.27 (IO2), U3.2 (DO(IO1))
MOSI: D2.2, J1.P3 (CMD), J3.14, R3.1, TP7.TP, U1.7 (IO7), U3.5 (DI(IO0))
unnamed: CHG_LED.C, R1_BAT.2
unnamed: D7.1 (CATHODE), R_CAPACITOR.2
unnamed: C_DELAY.1, IC2.5 (CT)
unnamed: C1_BAT1.1, DMG2305UX-7.2 (S), IC1.1 (VIN), IC1.3 (CE), SD0805S020S1R0.1 (CATHODE)
unnamed: MCP73831.5 (PROG), R2_BAT.2
unnamed: MCP73831.1 (STAT), R1_BAT.1
unnamed: EPD_C12.1, J3.24
unnamed: EPD_C7.1, J3.19
unnamed: EPD_C1.1, J3.4
unnamed: EPD_C2.1, J3.5
unnamed: EPD_C10.1, J3.22
unnamed: EPD_C8.1, J3.20
unnamed: C7.1, D9.1 (K), D10.2 (A)
unnamed: J4.B5, R2-USB.1
unnamed: J4.A5, R2-USB1.2
unnamed: EPD_C6.1, J3.18
PREVGH: D8.1 (K), EPD_C9.1, J3.21
PREVGL: D9.2 (A), EPD_C11.1, J3.23
RESE: J3.3, Q2.2 (S), R10.1
RESE': R8.2, R10.2, SJ1.2
RESET: C2.1, IC2.1 (VOUT), RESET_BUTTON.3, RESET_BUTTON.4, R_RESET.2, U1.3 (EN)
RTC_RST: U1.16 (IO18), U4.4 (!RST)
RX: TP2.TP, U1.24 (RXD0/GPIO17)
SCK: D3.2, J1.P5 (CLK), J3.13, R4.1, TP8.TP, U1.6 (IO6), U3.6 (CLK)
SCL: J2.4, R2-PINH.1, SENSOR2.4 (SCK), U1.20 (IO22), U2.7 (SCL), U4.16 (SCL)
SDA: J2.3, R1_PINH.1, SENSOR2.3 (SDI), U1.19 (IO21), U2.8 (SDA), U4.15 (SDA)
SRC: C7.2, D8.2 (A), L1.1, Q2.3 (D)
SS_SD: D6.2, J1.P2 (CD/DAT3), R7.1, U1.4 (IO4)
TX: TP1.TP, U1.25 (TXD0/GPIO16)
USB_D+: D11.1 (I/O1_1), U1.14 (IO13)
USB_D-: D11.3 (I/O2_1), U1.13 (IO12)
VBAT: C2_BAT.1, DMG2305UX-7.3 (D), MCP73831.3 (VBAT), TP3.TP, U2.2 (CELL), U2.3 (VDD)
VBUS: C1_BAT.1, C4_USB.1, C5_USB.1, CHG_LED.A, D11.5 (VBUS), DMG2305UX-7.1 (G), MCP73831.4 (VIN), PFMF.050.1.2, R1_PWRUSB.2, SD0805S020S1R0.2 (ANODE), TP14.TP
VRTC: C6.1, C10_SUPERCAP.2, R_CAPACITOR.1, U4.14 (VBAT)
VUSB: J4.A4, J4.A9, J4.B4, J4.B9, PFMF.050.1.1

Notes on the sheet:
drawn by: Ciocea Bogdan-Andrei
OpenBook Schematic
External NOR Flash 64MB
Battery Charge Level
SD Card
SPI ESD Protection Lines
Qwiic / Stemma QT
Test Pads
Voltage Supervisor + Reset & Boot / IO Button
ESP32 C6
RTC Module DS3231SN
USB C connector & ESD protection
LDO Voltage Regulator
Li-Po Battery Charging Controller
E-Paper Drive Circuit
Display Type Selector
Environmental Sensor BME688
EPD Power
E-Paper Display Header
3/20/2025 12:29 PM



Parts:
BOOT_BUTTON: BUTTON_CUSYOMV1; MYBUTTON
C1, C3, C4, C4_USB, C6, C8, C9: 100nF; EAGLE-LTSPICE_C0402
C1_BAT, C1_BAT1, C1_BAT2, C2_BAT, C5_USB: 4.7uF; EAGLE-LTSPICE_C0402
C2: 1uF; EAGLE-LTSPICE_C0402
C2-TANT: 100uF TANT; RCL_CT3528
C5: 10uF; EAGLE-LTSPICE_C0402
C7: 4.7uF/25V; EAGLE-LTSPICE_C0402
C10_SUPERCAP: CPH3225A; CAPCP3225X100N
CHANGE_BUTTON: BUTTON_CUSYOMV1; MYBUTTON
CHG_LED: ADAFRUIT_LEDCHIP-LED0603; ADAFRUIT_CHIP-LED0603
C_DELAY: 100nF; EAGLE-LTSPICE_C0402
D1, D2, D3, D4, D5, D6: PGB1010603MR; DIOC1608X36N
D7: SD0805S020S1R0; ESP32_WROVER_AVX---SD0805S020S1R0_AVX_SD0805S020S1R0_0
D8, D9, D10: MBR0530; SOD3716X135N
D11: USBLC6-2SC6Y; SOT95P280X145-6N
DMG2305UX-7: 20V/4.2A/52mΩ/1.4W; ESP32_WROVER_SPARKFUN-DISCRETESEMI_SOT23-3
EPD_C1, EPD_C2, EPD_C6, EPD_C7, EPD_C8, EPD_C9, EPD_C10, EPD_C11, EPD_C12: 1uF/50V; EAGLE-LTSPICE_C0402
EPD_C5: 0.1uF/50V; EAGLE-LTSPICE_C0402
IC1: XC6220A331MR-G; SOT95P280X120-5N
IC2: BD5229G-TR; SOT95P280X125-5N
J1: 112A-TAAR-R03_ATTEND; 112ATAARR03ATTEND
J2: QWIIC_RIGHT_ANGLE; JST04_1MM_RA
J3: FH34SRJ-24S-0.5SH_99_; FH34SRJ24S05SH99
J4: SAMACSYS_PARTS_USB4110-GF-A; SAMACSYS_PARTS_USB4110GFA
L1: 68uH; IND_4828-WE-TPC_WRE
MCP73831: ESP32_WROVER_SPARKFUN-IC-POWER_MCP73831; ESP32_WROVER_SPARKFUN-IC-POWER_SOT23-5
PFMF.050.1: ESP32C6_VARISTORCN1812; ESP32C6_VARISTOR_CT/CN1812
Q1: 20V/4.2A/52mΩ/1.4W; ESP32_WROVER_SPARKFUN-DISCRETESEMI_SOT23-3
Q2: SI1308EDL-T1-GE3; SOT65P210X110-3N
R1, R1_PINH, R1_PINH1, R2, R2-PINH, R2-PINH1, R3, R4, R5, R6, R7, R9: 10K; ESP32_WROVER_EAGLE-LTSPICE_R0402
R1_BAT: 200; ESP32_WROVER_EAGLE-LTSPICE_R0402
R1_PWRUSB: 100K; ESP32_WROVER_EAGLE-LTSPICE_R0402
R2-USB, R2-USB1: 5k1; ESP32_WROVER_EAGLE-LTSPICE_R0402
R2_BAT: 2K; ESP32_WROVER_EAGLE-LTSPICE_R0402
R8: 2.2; ESP32_WROVER_EAGLE-LTSPICE_R0402
R10: 0.47; ESP32_WROVER_EAGLE-LTSPICE_R0402
RESET_BUTTON: BUTTON_CUSYOMV1; MYBUTTON
R_BOOT: 10K; ESP32_WROVER_EAGLE-LTSPICE_R0402
R_CAPACITOR: 15; ESP32_WROVER_EAGLE-LTSPICE_R0402
R_CHANGE: 10K; ESP32_WROVER_EAGLE-LTSPICE_R0402
R_CL1: 10K; ESP32_WROVER_EAGLE-LTSPICE_R0402
R_RESET: 10K; ESP32_WROVER_EAGLE-LTSPICE_R0402
SD0805S020S1R0: ESP32_WROVER_AVX---SD0805S020S1R0_AVX_SD0805S020S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; ESP32_WROVER_AVX---SD0805S020S1R0_AVX_SD0805S020S1R0_0
SENSOR2: BME688; ESP32_WROVER_BME680_PSON80P300X300X100-8N
SJ1: SJ
TP1: TX; TP20R
TP2: RX; TP20R
TP3: VBAT; TP20R
TP4, TP5: GND; TP20R
TP6: MISO; TP20R
TP7: MOSI; TP20R
TP8: SCK; TP20R
TP9: EPD_BUSY; TP20R
TP10: EPD_CS; TP20R
TP11: EPD_DC; TP20R
TP12: EPD_RST; TP20R
TP13: EPD_3V3_C; TP20R
TP14: VBUS; TP20R
TP15: INT_RTC; TP20R
TP16: 3V3; TP20R
TP17: EPD_3V3; TP20R
U1: ESP32-C6-WROOM-1-N8; XCVR_ESP32-C6-WROOM-1-N8
U2: MAX17048G+T10; SON50P200X200X80-9N
U3: W25Q512JVEIQ; SON127P600X800X80-9N
U4: DS3231SN#; SOIC127P1032X265-16N

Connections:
3V3: C1.1, C1_BAT2.1, C2-TANT.+, D7.2 (ANODE), IC1.5 (VOUT), IC2.2 (VDD), J1.P4 (VDD), J2.2, Q1.3 (D), R1.1, R1_PINH1.2, R2.2, R2-PINH1.1, R3.2, R4.2, R5.2, R6.2, R7.2, R_BOOT.1, R_CHANGE.1, R_CL1.1, R_RESET.1, TP16.TP, U1.2 (3V3), U3.3 (!WP!(IO2)), U3.7 (!HOLD!/!RESET!(IO3)), U3.8 (VCC), U4.2 (VCC)
32KHZ: R2-PINH1.2, U1.9 (IO1), U4.1 (32KHZ)
DN: D11.4 (I/O2_2), J4.A7, J4.B7
DP: D11.6 (I/O1_2), J4.A6, J4.B6
EPD_3V3: C5.1, EPD_C5.1, J3.15, J3.16, L1.2, Q1.2 (S), TP17.TP
EPD_3V3_C: Q1.1 (G), R_CL1.2, TP13.TP, U1.18 (IO20)
EPD_BUSY: J3.9, TP9.TP, U1.26 (IO3)
EPD_CS: D5.2, J3.12, R6.1, TP10.TP, U1.11 (IO10)
EPD_DC: J3.11, TP11.TP, U1.5 (IO5)
EPD_RST: J3.10, TP12.TP, U1.21 (IO23)
FLASH_CS: D4.2, R5.1, U1.12 (IO11), U3.1 (!CS)
GDR: J3.2, Q2.1 (G), R9.1
GND: BOOT_BUTTON.1, BOOT_BUTTON.2, C1.2, C1_BAT.2, C1_BAT1.2, C1_BAT2.2, C2.2, C2-TANT.-, C2_BAT.2, C3.2, C4.2, C4_USB.2, C5.2, C5_USB.2, C6.2, C8.2, C9.2, C10_SUPERCAP.1, CHANGE_BUTTON.1, CHANGE_BUTTON.2, C_DELAY.2, D1.1, D2.1, D3.1, D4.1, D5.1, D6.1, D10.1 (K), D11.2 (GND), EPD_C1.2, EPD_C2.2, EPD_C5.2, EPD_C6.2, EPD_C7.2, EPD_C8.2, EPD_C9.2, EPD_C10.2, EPD_C11.2, EPD_C12.2, IC1.2 (VSS), IC2.3 (GND), J1.G1 (GND_1), J1.G2 (GND_2), J1.G3 (GND_3), J1.G4 (GND_4), J1.P6 (VSS), J2.1, J3.8, J3.17, J3.MP1, J3.MP2, J4.A1, J4.A12, J4.B1, J4.B12, J4.MP1, J4.MP2, J4.MP3, J4.MP4, MCP73831.2 (VSS), R1_PWRUSB.1, R2-USB.2, R2-USB1.1, R2_BAT.1, R8.1, R9.2, RESET_BUTTON.1, RESET_BUTTON.2, SENSOR2.1 (GND), SENSOR2.5 (SDO), SENSOR2.7 (GND), SJ1.1, TP4.TP, TP5.TP, U1.1 (GND), U1.28 (GND), U1.29_1 (GND), U1.29_2 (GND), U1.29_3 (GND), U1.29_4 (GND), U1.29_5 (GND), U1.29_6 (GND), U1.29_7 (GND), U1.29_8 (GND), U1.29_9 (GND), U2.1 (CTG), U2.4 (GND), U2.6 (QSTRT), U2.9 (EP), U3.4 (GND), U3.9 (EXP), U4.13 (GND)
GPIO8: R1.2, U1.10 (IO8)
I2C_PW: C8.1, C9.1, R1_PINH.2, R2-PINH.2, SENSOR2.2 (CSB), SENSOR2.6 (VDDIO), SENSOR2.8 (VDD), U1.17 (IO19)
INT_RTC: R1_PINH1.1, TP15.TP, U1.8 (IO0), U4.3 (SQW/!INT)
IO/BOOT: BOOT_BUTTON.3, BOOT_BUTTON.4, C3.1, R_BOOT.2, U1.15 (IO9)
IO/CHANGE: C4.1, CHANGE_BUTTON.3, CHANGE_BUTTON.4, R_CHANGE.2, U1.23 (IO15)
MISO: D1.2, J1.P7 (DAT0), R2.1, TP6.TP, U1.27 (IO2), U3.2 (DO(IO1))
MOSI: D2.2, J1.P3 (CMD), J3.14, R3.1, TP7.TP, U1.7 (IO7), U3.5 (DI(IO0))
unnamed: CHG_LED.C, R1_BAT.2
unnamed: D7.1 (CATHODE), R_CAPACITOR.2
unnamed: C_DELAY.1, IC2.5 (CT)
unnamed: C1_BAT1.1, DMG2305UX-7.2 (S), IC1.1 (VIN), IC1.3 (CE), SD0805S020S1R0.1 (CATHODE)
unnamed: MCP73831.5 (PROG), R2_BAT.2
unnamed: MCP73831.1 (STAT), R1_BAT.1
unnamed: EPD_C12.1, J3.24
unnamed: EPD_C7.1, J3.19
unnamed: EPD_C1.1, J3.4
unnamed: EPD_C2.1, J3.5
unnamed: EPD_C10.1, J3.22
unnamed: EPD_C8.1, J3.20
unnamed: C7.1, D9.1 (K), D10.2 (A)
unnamed: J4.B5, R2-USB.1
unnamed: J4.A5, R2-USB1.2
unnamed: EPD_C6.1, J3.18
PREVGH: D8.1 (K), EPD_C9.1, J3.21
PREVGL: D9.2 (A), EPD_C11.1, J3.23
RESE: J3.3, Q2.2 (S), R10.1
RESE': R8.2, R10.2, SJ1.2
RESET: C2.1, IC2.1 (VOUT), RESET_BUTTON.3, RESET_BUTTON.4, R_RESET.2, U1.3 (EN)
RTC_RST: U1.16 (IO18), U4.4 (!RST)
RX: TP2.TP, U1.24 (RXD0/GPIO17)
SCK: D3.2, J1.P5 (CLK), J3.13, R4.1, TP8.TP, U1.6 (IO6), U3.6 (CLK)
SCL: J2.4, R2-PINH.1, SENSOR2.4 (SCK), U1.20 (IO22), U2.7 (SCL), U4.16 (SCL)
SDA: J2.3, R1_PINH.1, SENSOR2.3 (SDI), U1.19 (IO21), U2.8 (SDA), U4.15 (SDA)
SRC: C7.2, D8.2 (A), L1.1, Q2.3 (D)
SS_SD: D6.2, J1.P2 (CD/DAT3), R7.1, U1.4 (IO4)
TX: TP1.TP, U1.25 (TXD0/GPIO16)
USB_D+: D11.1 (I/O1_1), U1.14 (IO13)
USB_D-: D11.3 (I/O2_1), U1.13 (IO12)
VBAT: C2_BAT.1, DMG2305UX-7.3 (D), MCP73831.3 (VBAT), TP3.TP, U2.2 (CELL), U2.3 (VDD)
VBUS: C1_BAT.1, C4_USB.1, C5_USB.1, CHG_LED.A, D11.5 (VBUS), DMG2305UX-7.1 (G), MCP73831.4 (VIN), PFMF.050.1.2, R1_PWRUSB.2, SD0805S020S1R0.2 (ANODE), TP14.TP
VRTC: C6.1, C10_SUPERCAP.2, R_CAPACITOR.1, U4.14 (VBAT)
VUSB: J4.A4, J4.A9, J4.B4, J4.B9, PFMF.050.1.1

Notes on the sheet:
drawn by: Ciocea Bogdan-Andrei
OpenBook Schematic
External NOR Flash 64MB
Battery Charge Level
SD Card
SPI ESD Protection Lines
Qwiic / Stemma QT
Test Pads
Voltage Supervisor + Reset & Boot / IO Button
ESP32 C6
RTC Module DS3231SN
USB C connector & ESD protection
LDO Voltage Regulator
Li-Po Battery Charging Controller
E-Paper Drive Circuit
Display Type Selector
Environmental Sensor BME688
EPD Power
E-Paper Display Header
3/20/2025 12:29 PM

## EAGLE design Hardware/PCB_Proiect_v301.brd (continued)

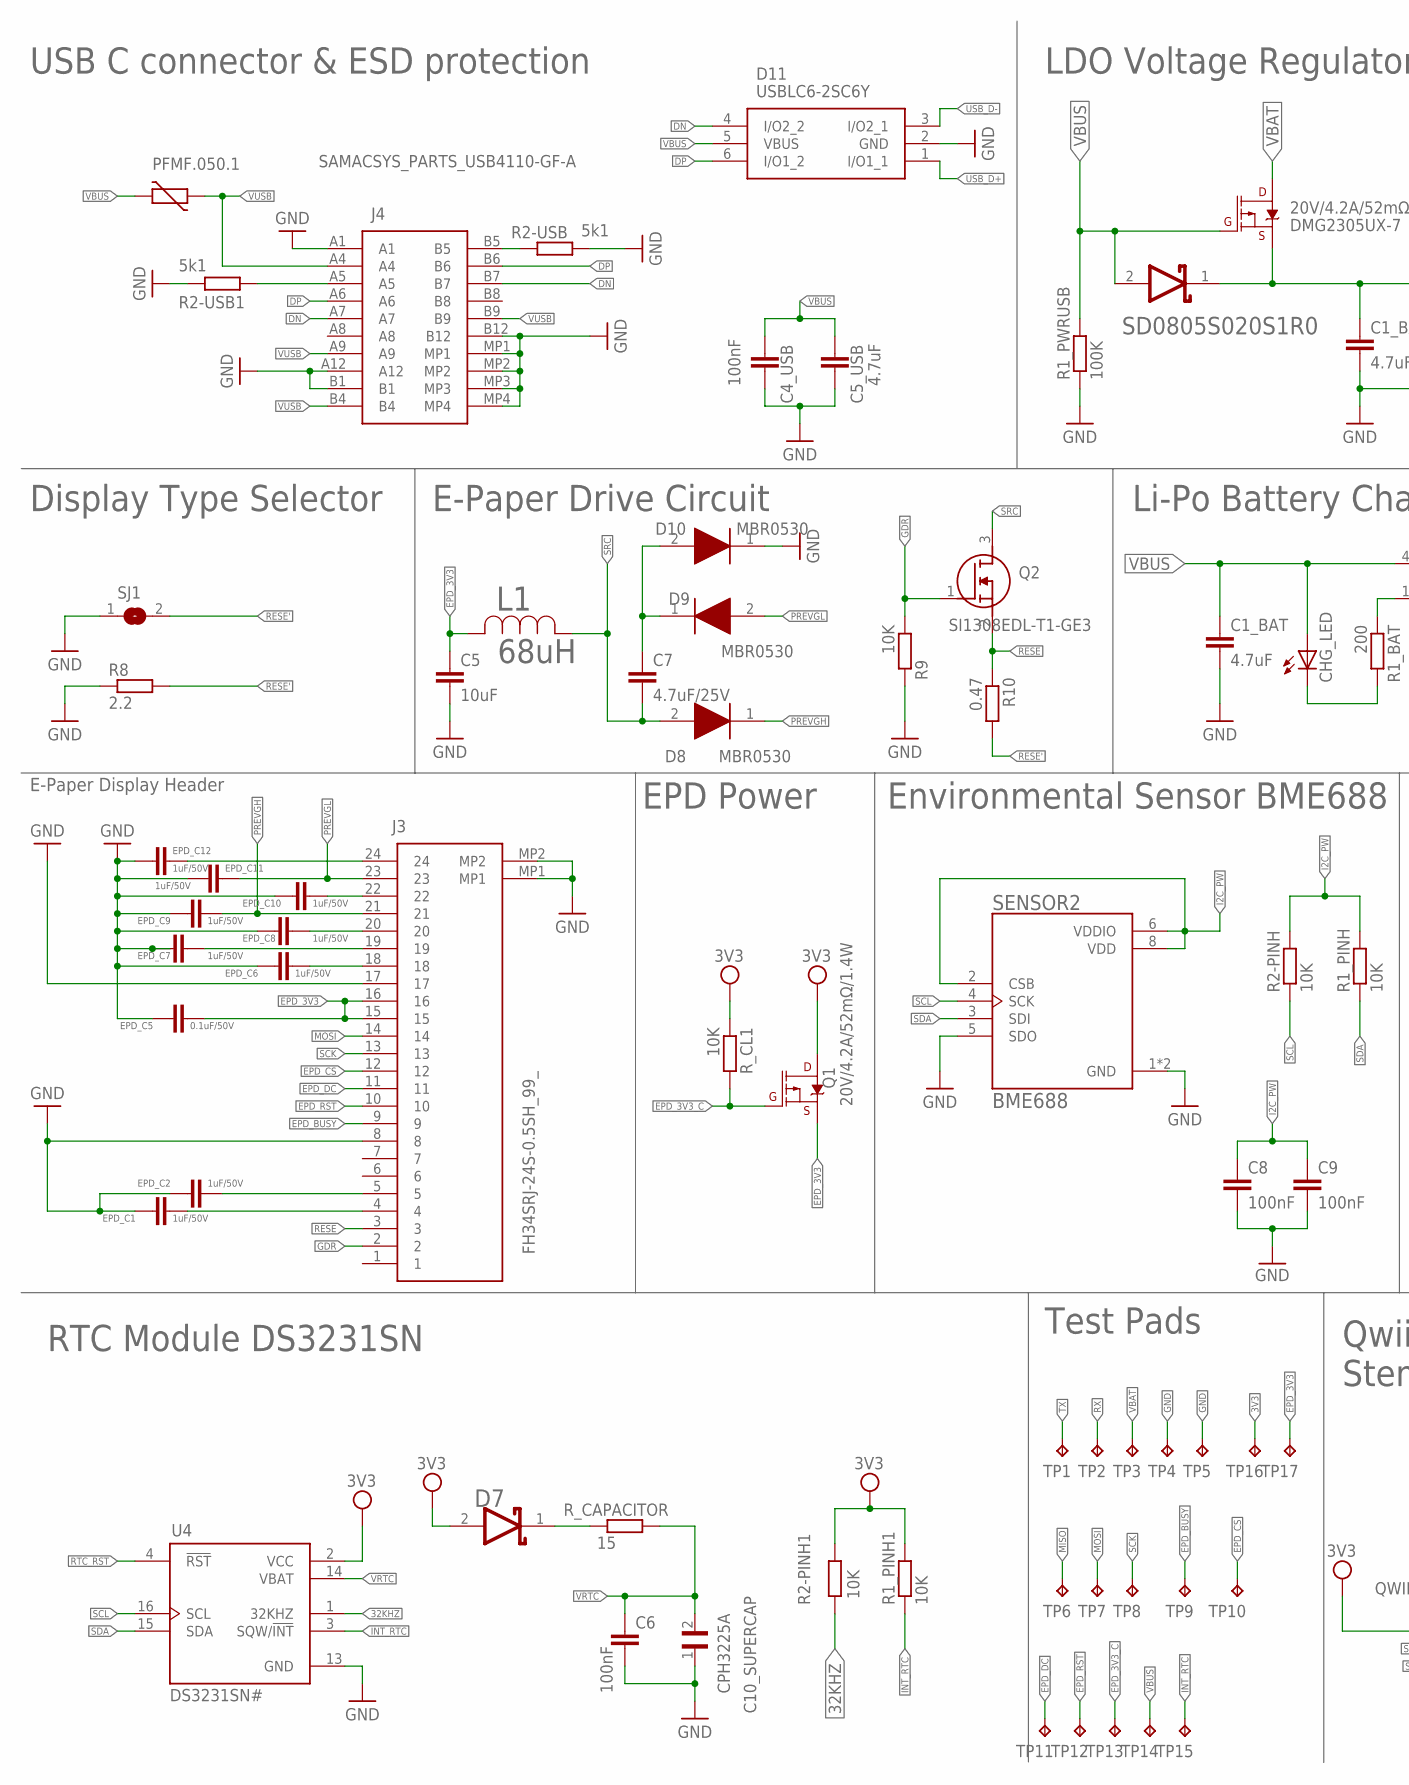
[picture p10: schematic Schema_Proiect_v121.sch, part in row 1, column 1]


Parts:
BOOT_BUTTON: BUTTON_CUSYOMV1; MYBUTTON
C1, C3, C4, C4_USB, C6, C8, C9: 100nF; EAGLE-LTSPICE_C0402
C1_BAT, C1_BAT1, C1_BAT2, C2_BAT, C5_USB: 4.7uF; EAGLE-LTSPICE_C0402
C2: 1uF; EAGLE-LTSPICE_C0402
C2-TANT: 100uF TANT; RCL_CT3528
C5: 10uF; EAGLE-LTSPICE_C0402
C7: 4.7uF/25V; EAGLE-LTSPICE_C0402
C10_SUPERCAP: CPH3225A; CAPCP3225X100N
CHANGE_BUTTON: BUTTON_CUSYOMV1; MYBUTTON
CHG_LED: ADAFRUIT_LEDCHIP-LED0603; ADAFRUIT_CHIP-LED0603
C_DELAY: 100nF; EAGLE-LTSPICE_C0402
D1, D2, D3, D4, D5, D6: PGB1010603MR; DIOC1608X36N
D7: SD0805S020S1R0; ESP32_WROVER_AVX---SD0805S020S1R0_AVX_SD0805S020S1R0_0
D8, D9, D10: MBR0530; SOD3716X135N
D11: USBLC6-2SC6Y; SOT95P280X145-6N
DMG2305UX-7: 20V/4.2A/52mΩ/1.4W; ESP32_WROVER_SPARKFUN-DISCRETESEMI_SOT23-3
EPD_C1, EPD_C2, EPD_C6, EPD_C7, EPD_C8, EPD_C9, EPD_C10, EPD_C11, EPD_C12: 1uF/50V; EAGLE-LTSPICE_C0402
EPD_C5: 0.1uF/50V; EAGLE-LTSPICE_C0402
IC1: XC6220A331MR-G; SOT95P280X120-5N
IC2: BD5229G-TR; SOT95P280X125-5N
J1: 112A-TAAR-R03_ATTEND; 112ATAARR03ATTEND
J2: QWIIC_RIGHT_ANGLE; JST04_1MM_RA
J3: FH34SRJ-24S-0.5SH_99_; FH34SRJ24S05SH99
J4: SAMACSYS_PARTS_USB4110-GF-A; SAMACSYS_PARTS_USB4110GFA
L1: 68uH; IND_4828-WE-TPC_WRE
MCP73831: ESP32_WROVER_SPARKFUN-IC-POWER_MCP73831; ESP32_WROVER_SPARKFUN-IC-POWER_SOT23-5
PFMF.050.1: ESP32C6_VARISTORCN1812; ESP32C6_VARISTOR_CT/CN1812
Q1: 20V/4.2A/52mΩ/1.4W; ESP32_WROVER_SPARKFUN-DISCRETESEMI_SOT23-3
Q2: SI1308EDL-T1-GE3; SOT65P210X110-3N
R1, R1_PINH, R1_PINH1, R2, R2-PINH, R2-PINH1, R3, R4, R5, R6, R7, R9: 10K; ESP32_WROVER_EAGLE-LTSPICE_R0402
R1_BAT: 200; ESP32_WROVER_EAGLE-LTSPICE_R0402
R1_PWRUSB: 100K; ESP32_WROVER_EAGLE-LTSPICE_R0402
R2-USB, R2-USB1: 5k1; ESP32_WROVER_EAGLE-LTSPICE_R0402
R2_BAT: 2K; ESP32_WROVER_EAGLE-LTSPICE_R0402
R8: 2.2; ESP32_WROVER_EAGLE-LTSPICE_R0402
R10: 0.47; ESP32_WROVER_EAGLE-LTSPICE_R0402
RESET_BUTTON: BUTTON_CUSYOMV1; MYBUTTON
R_BOOT: 10K; ESP32_WROVER_EAGLE-LTSPICE_R0402
R_CAPACITOR: 15; ESP32_WROVER_EAGLE-LTSPICE_R0402
R_CHANGE: 10K; ESP32_WROVER_EAGLE-LTSPICE_R0402
R_CL1: 10K; ESP32_WROVER_EAGLE-LTSPICE_R0402
R_RESET: 10K; ESP32_WROVER_EAGLE-LTSPICE_R0402
SD0805S020S1R0: ESP32_WROVER_AVX---SD0805S020S1R0_AVX_SD0805S020S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; ESP32_WROVER_AVX---SD0805S020S1R0_AVX_SD0805S020S1R0_0
SENSOR2: BME688; ESP32_WROVER_BME680_PSON80P300X300X100-8N
SJ1: SJ
TP1: TX; TP20R
TP2: RX; TP20R
TP3: VBAT; TP20R
TP4, TP5: GND; TP20R
TP6: MISO; TP20R
TP7: MOSI; TP20R
TP8: SCK; TP20R
TP9: EPD_BUSY; TP20R
TP10: EPD_CS; TP20R
TP11: EPD_DC; TP20R
TP12: EPD_RST; TP20R
TP13: EPD_3V3_C; TP20R
TP14: VBUS; TP20R
TP15: INT_RTC; TP20R
TP16: 3V3; TP20R
TP17: EPD_3V3; TP20R
U1: ESP32-C6-WROOM-1-N8; XCVR_ESP32-C6-WROOM-1-N8
U2: MAX17048G+T10; SON50P200X200X80-9N
U3: W25Q512JVEIQ; SON127P600X800X80-9N
U4: DS3231SN#; SOIC127P1032X265-16N

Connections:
3V3: C1.1, C1_BAT2.1, C2-TANT.+, D7.2 (ANODE), IC1.5 (VOUT), IC2.2 (VDD), J1.P4 (VDD), J2.2, Q1.3 (D), R1.1, R1_PINH1.2, R2.2, R2-PINH1.1, R3.2, R4.2, R5.2, R6.2, R7.2, R_BOOT.1, R_CHANGE.1, R_CL1.1, R_RESET.1, TP16.TP, U1.2 (3V3), U3.3 (!WP!(IO2)), U3.7 (!HOLD!/!RESET!(IO3)), U3.8 (VCC), U4.2 (VCC)
32KHZ: R2-PINH1.2, U1.9 (IO1), U4.1 (32KHZ)
DN: D11.4 (I/O2_2), J4.A7, J4.B7
DP: D11.6 (I/O1_2), J4.A6, J4.B6
EPD_3V3: C5.1, EPD_C5.1, J3.15, J3.16, L1.2, Q1.2 (S), TP17.TP
EPD_3V3_C: Q1.1 (G), R_CL1.2, TP13.TP, U1.18 (IO20)
EPD_BUSY: J3.9, TP9.TP, U1.26 (IO3)
EPD_CS: D5.2, J3.12, R6.1, TP10.TP, U1.11 (IO10)
EPD_DC: J3.11, TP11.TP, U1.5 (IO5)
EPD_RST: J3.10, TP12.TP, U1.21 (IO23)
FLASH_CS: D4.2, R5.1, U1.12 (IO11), U3.1 (!CS)
GDR: J3.2, Q2.1 (G), R9.1
GND: BOOT_BUTTON.1, BOOT_BUTTON.2, C1.2, C1_BAT.2, C1_BAT1.2, C1_BAT2.2, C2.2, C2-TANT.-, C2_BAT.2, C3.2, C4.2, C4_USB.2, C5.2, C5_USB.2, C6.2, C8.2, C9.2, C10_SUPERCAP.1, CHANGE_BUTTON.1, CHANGE_BUTTON.2, C_DELAY.2, D1.1, D2.1, D3.1, D4.1, D5.1, D6.1, D10.1 (K), D11.2 (GND), EPD_C1.2, EPD_C2.2, EPD_C5.2, EPD_C6.2, EPD_C7.2, EPD_C8.2, EPD_C9.2, EPD_C10.2, EPD_C11.2, EPD_C12.2, IC1.2 (VSS), IC2.3 (GND), J1.G1 (GND_1), J1.G2 (GND_2), J1.G3 (GND_3), J1.G4 (GND_4), J1.P6 (VSS), J2.1, J3.8, J3.17, J3.MP1, J3.MP2, J4.A1, J4.A12, J4.B1, J4.B12, J4.MP1, J4.MP2, J4.MP3, J4.MP4, MCP73831.2 (VSS), R1_PWRUSB.1, R2-USB.2, R2-USB1.1, R2_BAT.1, R8.1, R9.2, RESET_BUTTON.1, RESET_BUTTON.2, SENSOR2.1 (GND), SENSOR2.5 (SDO), SENSOR2.7 (GND), SJ1.1, TP4.TP, TP5.TP, U1.1 (GND), U1.28 (GND), U1.29_1 (GND), U1.29_2 (GND), U1.29_3 (GND), U1.29_4 (GND), U1.29_5 (GND), U1.29_6 (GND), U1.29_7 (GND), U1.29_8 (GND), U1.29_9 (GND), U2.1 (CTG), U2.4 (GND), U2.6 (QSTRT), U2.9 (EP), U3.4 (GND), U3.9 (EXP), U4.13 (GND)
GPIO8: R1.2, U1.10 (IO8)
I2C_PW: C8.1, C9.1, R1_PINH.2, R2-PINH.2, SENSOR2.2 (CSB), SENSOR2.6 (VDDIO), SENSOR2.8 (VDD), U1.17 (IO19)
INT_RTC: R1_PINH1.1, TP15.TP, U1.8 (IO0), U4.3 (SQW/!INT)
IO/BOOT: BOOT_BUTTON.3, BOOT_BUTTON.4, C3.1, R_BOOT.2, U1.15 (IO9)
IO/CHANGE: C4.1, CHANGE_BUTTON.3, CHANGE_BUTTON.4, R_CHANGE.2, U1.23 (IO15)
MISO: D1.2, J1.P7 (DAT0), R2.1, TP6.TP, U1.27 (IO2), U3.2 (DO(IO1))
MOSI: D2.2, J1.P3 (CMD), J3.14, R3.1, TP7.TP, U1.7 (IO7), U3.5 (DI(IO0))
unnamed: CHG_LED.C, R1_BAT.2
unnamed: D7.1 (CATHODE), R_CAPACITOR.2
unnamed: C_DELAY.1, IC2.5 (CT)
unnamed: C1_BAT1.1, DMG2305UX-7.2 (S), IC1.1 (VIN), IC1.3 (CE), SD0805S020S1R0.1 (CATHODE)
unnamed: MCP73831.5 (PROG), R2_BAT.2
unnamed: MCP73831.1 (STAT), R1_BAT.1
unnamed: EPD_C12.1, J3.24
unnamed: EPD_C7.1, J3.19
unnamed: EPD_C1.1, J3.4
unnamed: EPD_C2.1, J3.5
unnamed: EPD_C10.1, J3.22
unnamed: EPD_C8.1, J3.20
unnamed: C7.1, D9.1 (K), D10.2 (A)
unnamed: J4.B5, R2-USB.1
unnamed: J4.A5, R2-USB1.2
unnamed: EPD_C6.1, J3.18
PREVGH: D8.1 (K), EPD_C9.1, J3.21
PREVGL: D9.2 (A), EPD_C11.1, J3.23
RESE: J3.3, Q2.2 (S), R10.1
RESE': R8.2, R10.2, SJ1.2
RESET: C2.1, IC2.1 (VOUT), RESET_BUTTON.3, RESET_BUTTON.4, R_RESET.2, U1.3 (EN)
RTC_RST: U1.16 (IO18), U4.4 (!RST)
RX: TP2.TP, U1.24 (RXD0/GPIO17)
SCK: D3.2, J1.P5 (CLK), J3.13, R4.1, TP8.TP, U1.6 (IO6), U3.6 (CLK)
SCL: J2.4, R2-PINH.1, SENSOR2.4 (SCK), U1.20 (IO22), U2.7 (SCL), U4.16 (SCL)
SDA: J2.3, R1_PINH.1, SENSOR2.3 (SDI), U1.19 (IO21), U2.8 (SDA), U4.15 (SDA)
SRC: C7.2, D8.2 (A), L1.1, Q2.3 (D)
SS_SD: D6.2, J1.P2 (CD/DAT3), R7.1, U1.4 (IO4)
TX: TP1.TP, U1.25 (TXD0/GPIO16)
USB_D+: D11.1 (I/O1_1), U1.14 (IO13)
USB_D-: D11.3 (I/O2_1), U1.13 (IO12)
VBAT: C2_BAT.1, DMG2305UX-7.3 (D), MCP73831.3 (VBAT), TP3.TP, U2.2 (CELL), U2.3 (VDD)
VBUS: C1_BAT.1, C4_USB.1, C5_USB.1, CHG_LED.A, D11.5 (VBUS), DMG2305UX-7.1 (G), MCP73831.4 (VIN), PFMF.050.1.2, R1_PWRUSB.2, SD0805S020S1R0.2 (ANODE), TP14.TP
VRTC: C6.1, C10_SUPERCAP.2, R_CAPACITOR.1, U4.14 (VBAT)
VUSB: J4.A4, J4.A9, J4.B4, J4.B9, PFMF.050.1.1

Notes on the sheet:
drawn by: Ciocea Bogdan-Andrei
OpenBook Schematic
External NOR Flash 64MB
Battery Charge Level
SD Card
SPI ESD Protection Lines
Qwiic / Stemma QT
Test Pads
Voltage Supervisor + Reset & Boot / IO Button
ESP32 C6
RTC Module DS3231SN
USB C connector & ESD protection
LDO Voltage Regulator
Li-Po Battery Charging Controller
E-Paper Drive Circuit
Display Type Selector
Environmental Sensor BME688
EPD Power
E-Paper Display Header
3/20/2025 12:29 PM

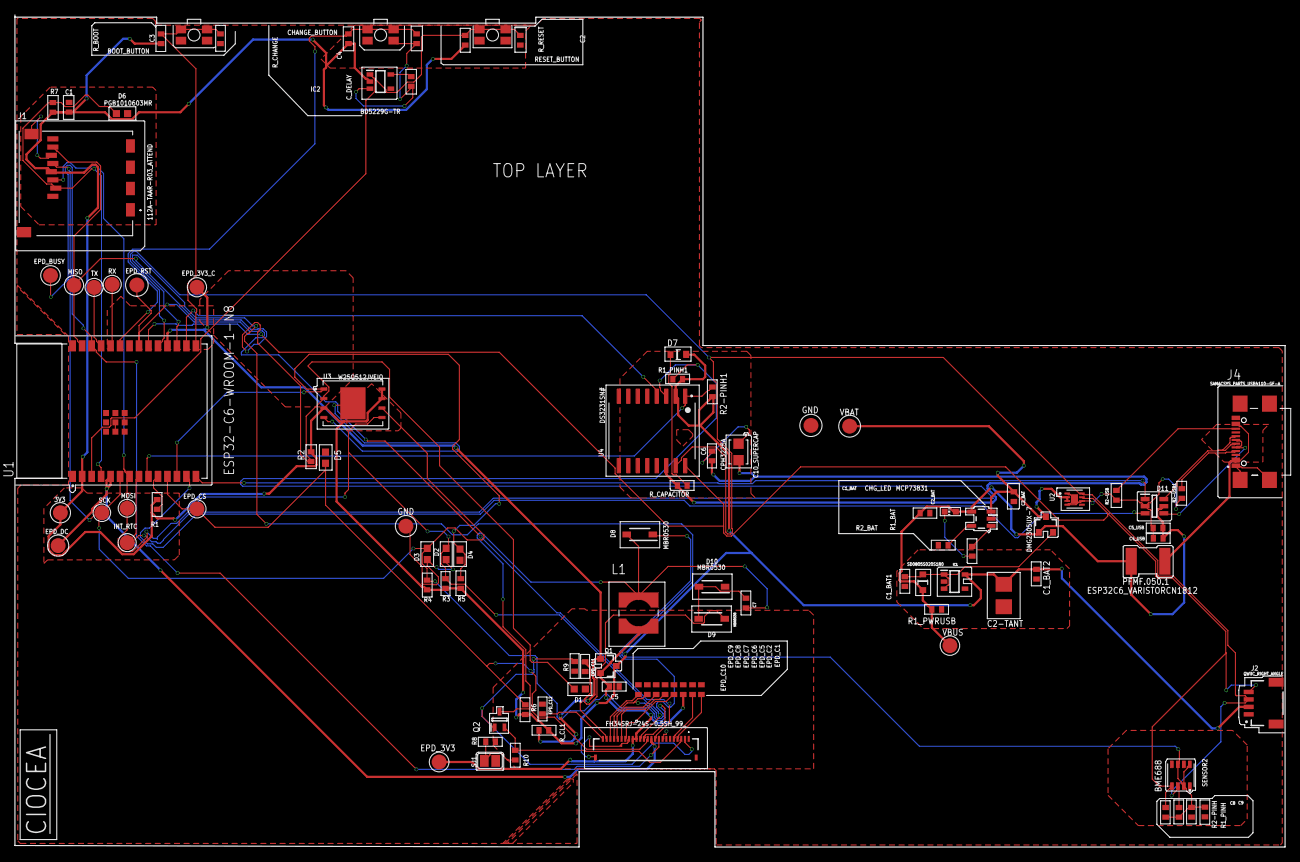
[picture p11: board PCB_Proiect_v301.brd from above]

Board: 2 copper layers, 170.2 x 111.2 mm, 103 parts (0 on the bottom side), 55 nets.

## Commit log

2025-03-23 Update repository
    [PCB.brd, Schematic.sch]
2025-03-29 Added a ton of things (3D Models, bom file...etc)
    [PCB Proiect v274.brd, PCB Proiect v274.csv, PCB.brd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]
2025-04-02 RETURN OF THE COMMITS
    [PCB Proiect v274.brd, PCB_Proiect_v283.brd]
2025-04-02 THE COMMIT STRIKES BACK
    [Schema_Proiect_v120.sch]
2025-04-04 Attack of the commits
    [PCB Proiect v283.csv, PnP_PCB Proiect v283_front.csv]
2025-04-10 Issue #1
    [PCB_Proiect_v283.brd, PCB_Proiect_v288.brd]
2025-04-10 Pentru #2
    [Schema_Proiect_v121.sch]
2025-04-11 For #3
    [PCB_Proiect_v290.brd]
2025-04-11 Issues #4 and #5
    [PCB Proiect v299.brd, PCB_Proiect_v290.brd]

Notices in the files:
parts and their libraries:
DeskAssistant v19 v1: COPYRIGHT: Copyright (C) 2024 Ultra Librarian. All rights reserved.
